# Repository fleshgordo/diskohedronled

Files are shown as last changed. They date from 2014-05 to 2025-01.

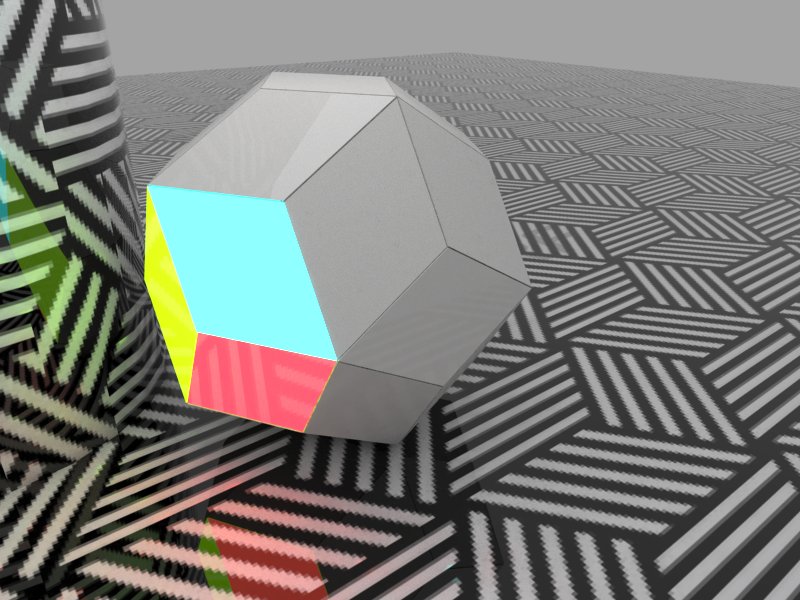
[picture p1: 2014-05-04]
construction/3dmodel/visualization/render-rgb-01.jpg

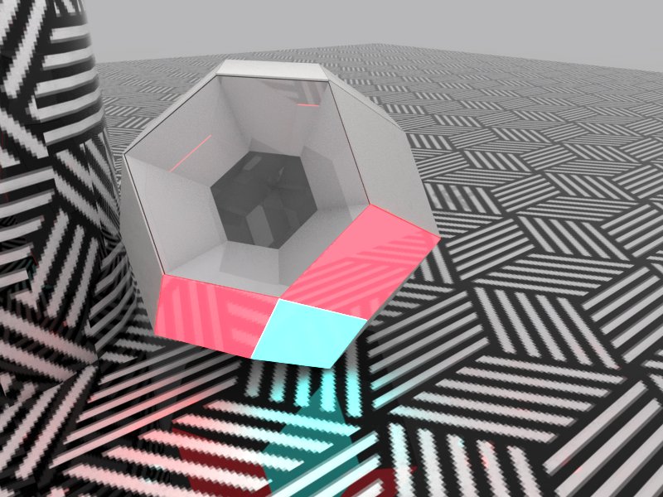
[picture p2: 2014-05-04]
construction/3dmodel/visualization/render-rgb-open.jpg

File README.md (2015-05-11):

Diskohedronled
==============

Diskohedron (led version) 2014

A triacontahedron with 30 laser-etched rhombic faces, each containing a 4W RGBW(+White) LED. The first prototype consists of 30 3d-printed rhombic boxes which form a Triacontahedron. 

  * 30 x 4W RGBW
  * WIFI interface (android/iphone controllable, served by nodejs on beaglebone black)
  * Modular
  
Thanks to Bread'n'Butter in Lausanne and HEAD Option interaction in Geneva for making us use their Makerbot printers.

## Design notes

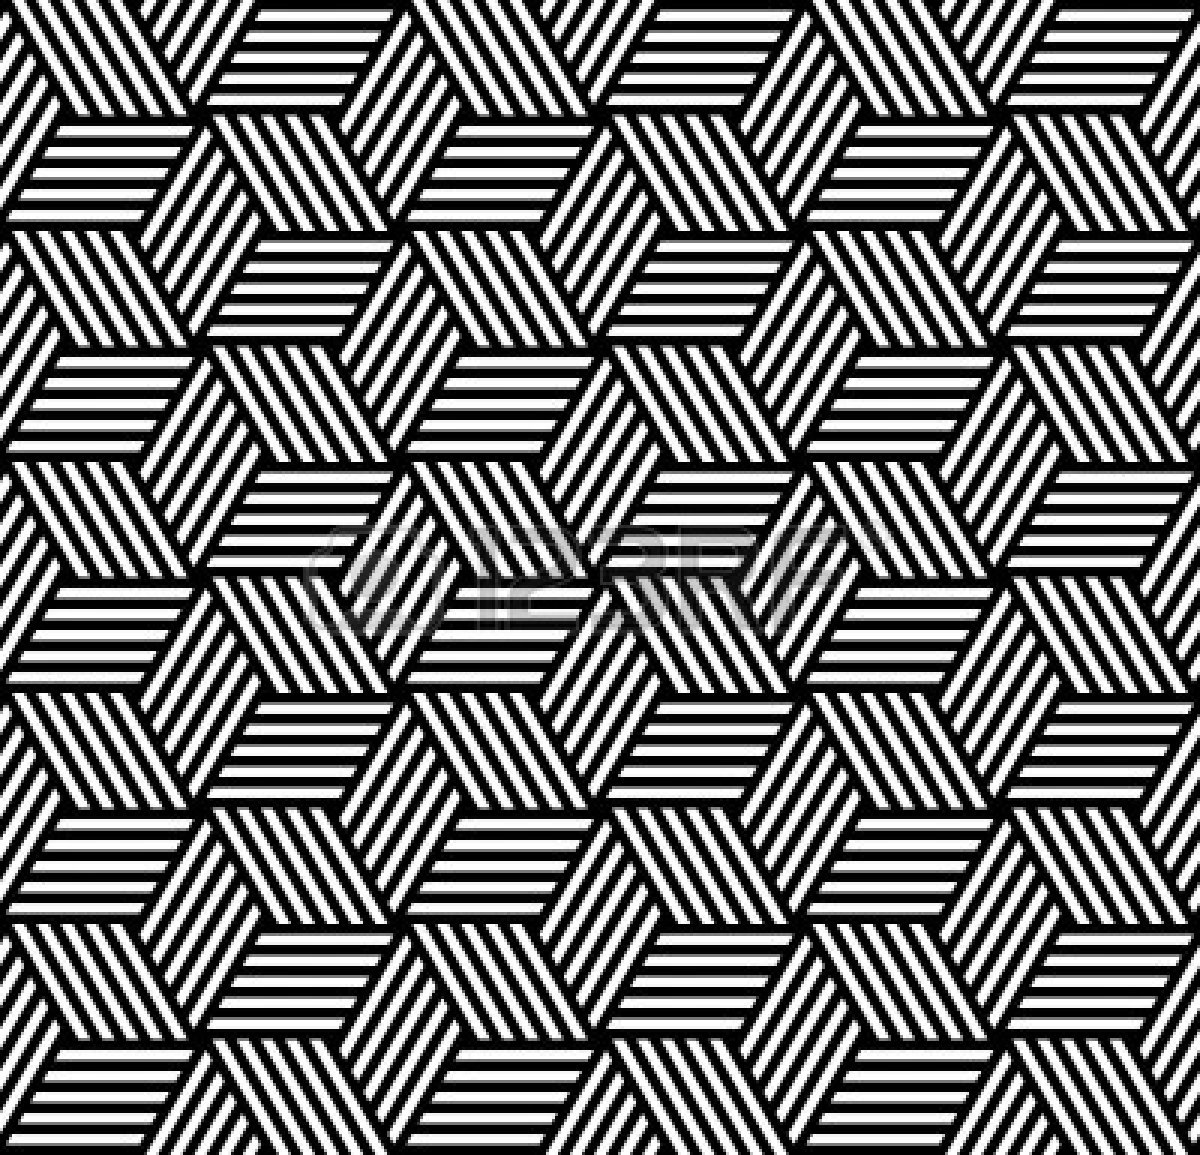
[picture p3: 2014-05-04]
construction/3dmodel/visualization/nahtlose-geometrische-muster-im-op-art-design.jpg

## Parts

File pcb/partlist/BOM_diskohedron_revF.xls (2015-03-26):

Ref | Value | Footprint | Manufacture | Manufacture Part Number | Quantity | Specification (mouser#)
1D | SN65LVDS1 | SOT23-5 | Texas Instruments | SN65LVDS1DBVR | 1 | 595-SN65LVDS1DBVR
4R | DS26LV32AT | SOIC16 | Texas Instruments | DS26LV32ATM/NOPB | 1 | 926-DS26LV32ATM/NOPB
C1 | 330uF | case G 10x10.2 | Panasonic | EEEFK1V331GP | 1 | 667-EEE-FK1V331GP
C2 | 330uF | case G 10x10.2 | Panasonic | EEEFK1V331GP | 1 | 667-EEE-FK1V331GP
C3 | 100n | C0805 | Vishay | VJ0805V104MXBP | 1 | 77-VJ0805V104MXBPBC
C4 | 100n | C0805 | Vishay | VJ0805V104MXBP | 1 | 77-VJ0805V104MXBPBC
D1 | 1N5824 3A | DIODE_SMC | Vishay | SS36-E3/57T | 1 | 625-SS36-E3
D2 | 1n4001 | SMADIODE | Taiwan Semiconductor | S1B | 1 | 512-S1B
JST | 8PIN-ZH | B8B-ZH |  | - | 1
L1 | 30uH | DR127 | Bussmann / Eaton | DR127-331-R | 1 | 704-DR127-331-R
LM2586 | LM2596 | TO263-5 | Texas Instruments | LM2596SX-3.3/NOPB | 1 | 926-LM2596SX33NOPB
R1 | 220R | M0805 | Vishay | CRCW0805220RF | 1 | 71-CRCW0805-220-E3
STP04 | STP04CM05 | TSSOP16 | STMicroelectronics | STP04CM0 | 1 | 511-STP04CM05XTTR
F1 | fuse | 1812 | Littelfuse | 1812L020PR | 1 | 576-1812L020PR
OUT-R | HERMAPHRODITMINI6PIN | HERMAPHRODITMINI6PIN | TE Connectivity | 1971567-3 | 1 | 571-1971567-3
POWEROUT-R | HERMAPHRODIT2PIN | HERMAPHRODIT2PIN | TE Connectivity | 1954289-1 | 1 | 571-1954289-1
IN1 | HERMAPHRODITMINI6PIN | HERMAPHRODITMINI6PIN | TE Connectivity | 1971567-3 | 1 | 571-1971567-3
POWERIN | HERMAPHRODIT2PIN | HERMAPHRODIT2PIN | TE Connectivity | 1954289-1 | 1 | 571-1954289-1

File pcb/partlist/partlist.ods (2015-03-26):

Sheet: costs_revd
Partlist
Exported from diskohedron4w_revd.sch at 15/11/14 8:38 AM
Part | Value | Device | Price | Package | Library | Mouser# | Manufactu
1D | SN65LVDS1 | SN65LVDS1 | $1.08 | SOT23-5 | diskohedron
4D | DS26LV31T | DS26LV31T |  | SOIC127P600X175-16N | Texas Instruments
4R | DS26LV32AT | DS26LV32AT | $1.39 | SOIC16 | diskohedron
C1 | 220uF | CPOL-EU175TMP-0810 | $0.28 | 175TMP-0810 | rcl | 140-VE221M1VTR0810 | VE-221M1VTR | http://www.ebay.com/itm/50-PCS-220UF-35V-SMD-Electrolytic-Capacitor-35V-220UF-8-10-/301202278340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
C2 | 220uF | CPOL-EU175TMP-0810 | $0.28 | 175TMP-0810 | rcl | 140-VE221M1VTR0810 | VE-221M1VTR
C3 | 100n | C-EUC0805 | $0.02 | C0805 | rcl | 77-VJ0805V104MXBPBC | VJ0805V104MXBP | http://www.ebay.com/itm/SMD-Chip-Capacitor-0805B104K-100nF-50V-100PCS-/371056581416?pt=LH_DefaultDomain_0
C4 | 100n | C-EUC0805 | $0.02 | C0805 | rcl | 77-VJ0805V104MXBPBC | VJ0805V104MXBP
D1 | 1N5824 3A | DIODE_E-SMC | $0.13 | DIODE_SMC | eagle-ltspice | 625-SS36-E3 | SS36-E3/57T
D2 | 1n4001 | DIODESMA | $0.03 | SMADIODE | adafruit | 821-S1BB | S1BB
JP1 | EXTBRD | M05PTH | $0.01 | 1X05 | SparkFun-Connectors
JST | 8PIN-ZH | 8PIN-ZH | $0.73 | B8B-ZH | diskohedron |  |  | http://www.ebay.com/itm/Micro-JST-1-5-ZH-8-Pin-Connector-Plug-with-Wire-x-10-sets-/121338507740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
L1 | 30uH | DR127 | $0.25 | DR127 | inductors | 704-DR127-331-R | DR127-331-R
LM2586 | LM2596 | LM2596S | $0.36 | TO263-5 | linear | 926-LM2596SX33NOPB | LM2596SX-3.3/NOPB | http://www.ebay.com/itm/50-PCS-LM2576S-3-3-TO-263-Step-Down-Voltage-Regulator-/301202266288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
R1 | 220R | R-EU_M0805 | $0.02 | M0805 | resistor | 71-CRCW0805-220-E3 | CRCW0805220RF | http://www.ebay.com/itm/50-220R-220-ohm-ohms-SMD-0805-Chip-Resistors-Surface-Mount-watts-5-/380905325760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
STP04 | STP04CM05 | STP04CM05 | $1.50 | TSSOP16 | stp04 | 511-STP04CM05XTTR | STP04CM0
IN1 | HERMAPHRODITMINI6PIN | HERMAPHRODITMINI6PIN | $0.50 | HERMAPHRODITMINI6PIN | diskohedron | 571-1971567-3 | 1971567-3
OUT-L | HERMAPHRODITMINI6PIN | HERMAPHRODITMINI6PIN | $0.50 | HERMAPHRODITMINI6PIN | diskohedron | 571-1971567-3 | 1971567-3
OUT-R | HERMAPHRODITMINI6PIN | HERMAPHRODITMINI6PIN |  | HERMAPHRODITMINI6PIN | diskohedron | 571-1971567-3 | 1971567-3
U$6 | HERMAPHRODIT2PIN | HERMAPHRODIT2PIN | $0.56 | HERMAPHRODIT2PIN | diskohedron | 571-1954289-1 | 1954289-1
U$7 | HERMAPHRODIT2PIN | HERMAPHRODIT2PIN | $0.56 | HERMAPHRODIT2PIN | diskohedron | 571-1954289-1 | 1954289-1
U$12 | HERMAPHRODIT2PIN | HERMAPHRODIT2PIN |  | HERMAPHRODIT2PIN | diskohedron | 571-1954289-1 | 1954289-1
F1 | FUSE | FUSE | $0.15 | 1812 | adafruit | 504-PTS181230V020 | PTS181230V020
 | 4W RGBW |  | $1.26
 | HEATSINK |  | $1.58
 | PLA-white 96g |  | $3.60
 | Acryl-glass Laser-cut |  | $3.00
 | PCB manufacturing |  | $4.20
 |  | Total par piece | $22.00
 |  | 30 pieces | $660.04
 |  | Power supply | $83.39
 |  | Microcontroller | $40.00
 |  | Cables, screws, glue | $20.00
 |  | Diskohedron in total | $825.43

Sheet: weight
 | in g
One module | 207
30 pcs. | 6210
Power supply | 325
Plastic Supply
Total | 6535

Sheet: costs_revb
Partlist
Exported from diskohedron4w_revb.sch at 6/4/14 8:38 AM
Part | Value | Device | Price | Package | Library | Mouser# | Manufactu
1D | SN65LVDS1 | SN65LVDS1 | $1.08 | SOT23-5 | diskohedron
4D | DS90LV047A | DS90LV047A |  |  | Texas Instruments
4R | DS26LV32AT | DS26LV32AT | $1.39 | SOIC16 | diskohedron
C1 | 220uF | CPOL-EU175TMP-0810 | $0.28 | 175TMP-0810 | rcl | 140-VE221M1VTR0810 | VE-221M1VTR | http://www.ebay.com/itm/50-PCS-220UF-35V-SMD-Electrolytic-Capacitor-35V-220UF-8-10-/301202278340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
C2 | 220uF | CPOL-EU175TMP-0810 | $0.28 | 175TMP-0810 | rcl | 140-VE221M1VTR0810 | VE-221M1VTR
C3 | 100n | C-EUC0805 | $0.02 | C0805 | rcl | 77-VJ0805V104MXBPBC | VJ0805V104MXBP | http://www.ebay.com/itm/SMD-Chip-Capacitor-0805B104K-100nF-50V-100PCS-/371056581416?pt=LH_DefaultDomain_0
C4 | 100n | C-EUC0805 | $0.02 | C0805 | rcl | 77-VJ0805V104MXBPBC | VJ0805V104MXBP
D1 | 1N5824 3A | DIODE_E-SMC | $0.13 | DIODE_SMC | eagle-ltspice | 625-SS36-E3 | SS36-E3/57T
D2 | 1n4001 | DIODESMA | $0.03 | SMADIODE | adafruit | 821-S1BB | S1BB
JP1 | EXTBRD | M05PTH | $0.01 | 1X05 | SparkFun-Connectors
JST | 8PIN-ZH | 8PIN-ZH | $0.73 | B8B-ZH | diskohedron | digikey 455-1663-ND | B8B-ZR(LF)(SN) | http://www.ebay.com/itm/Micro-JST-1-5-ZH-8-Pin-Connector-Plug-with-Wire-x-10-sets-/121338507740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
L1 | 30uH | DR127 | $0.25 | DR127 | inductors | 704-DR127-331-R | DR127-331-R
LM2586 | LM2596 | LM2596S | $0.36 | TO263-5 | linear | 926-LM2596SX33NOPB | LM2596SX-3.3/NOPB | http://www.ebay.com/itm/50-PCS-LM2576S-3-3-TO-263-Step-Down-Voltage-Regulator-/301202266288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
R1 | 220R | R-EU_M0805 | $0.02 | M0805 | resistor | 71-CRCW0805-220-E3 | CRCW0805220RF | http://www.ebay.com/itm/50-220R-220-ohm-ohms-SMD-0805-Chip-Resistors-Surface-Mount-watts-5-/380905325760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
STP04 | STP04CM05 | STP04CM05 | $1.50 | TSSOP16 | stp04 | 511-STP04CM05XTTR | STP04CM0
IN1 | HERMAPHRODITMINI6PIN | HERMAPHRODITMINI6PIN | $0.50 | HERMAPHRODITMINI6PIN | diskohedron | 571-1971567-3 | 1971567-3
OUT-L | HERMAPHRODITMINI6PIN | HERMAPHRODITMINI6PIN | $0.50 | HERMAPHRODITMINI6PIN | diskohedron | 571-1971567-3 | 1971567-3
OUT-R | HERMAPHRODITMINI6PIN | HERMAPHRODITMINI6PIN |  | HERMAPHRODITMINI6PIN | diskohedron | 571-1971567-3 | 1971567-3
U$6 | HERMAPHRODIT2PIN | HERMAPHRODIT2PIN | $0.56 | HERMAPHRODIT2PIN | diskohedron | 571-1954289-1 | 1954289-1
U$7 | HERMAPHRODIT2PIN | HERMAPHRODIT2PIN | $0.56 | HERMAPHRODIT2PIN | diskohedron | 571-1954289-1 | 1954289-1
U$12 | HERMAPHRODIT2PIN | HERMAPHRODIT2PIN |  | HERMAPHRODIT2PIN | diskohedron | 571-1954289-1 | 1954289-1
 | 4W RGBW
 | HEATSINK
 | PLA-white 96g
 | Acryl-glass Laser-cut
 | PCB manufacturing |  | $4.20
 | PCB Assembly
 |  | Total par piece | $12.41
 |  | 30 pieces | $372.43
 |  | Power supply | $83.39
 |  | Microcontroller | $40.00
 |  | Cables, screws, glue | $20.00
 |  | Diskohedron in total | $528.23

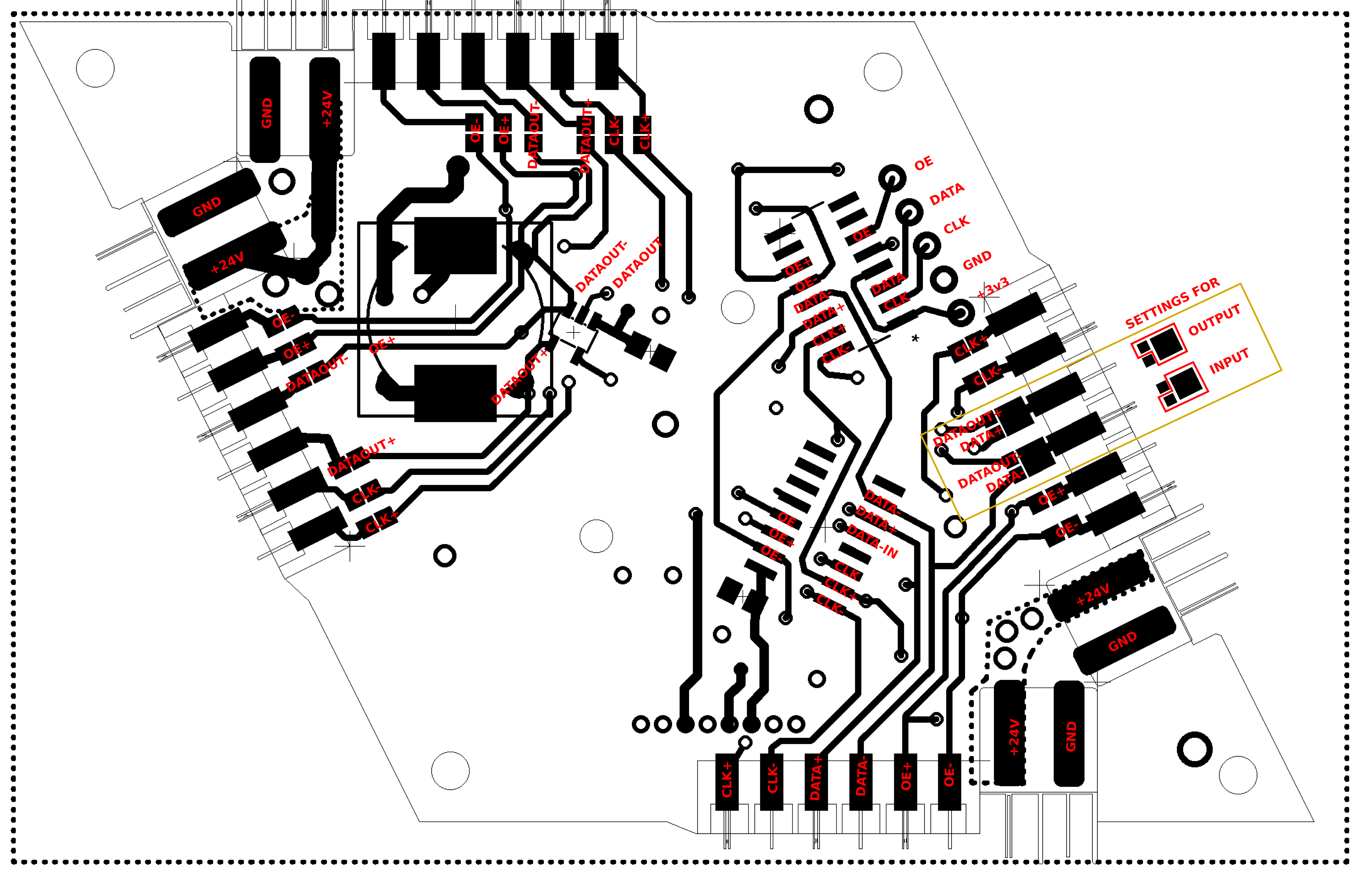
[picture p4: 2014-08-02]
pcb/partlist/MountingBottomrevc.png

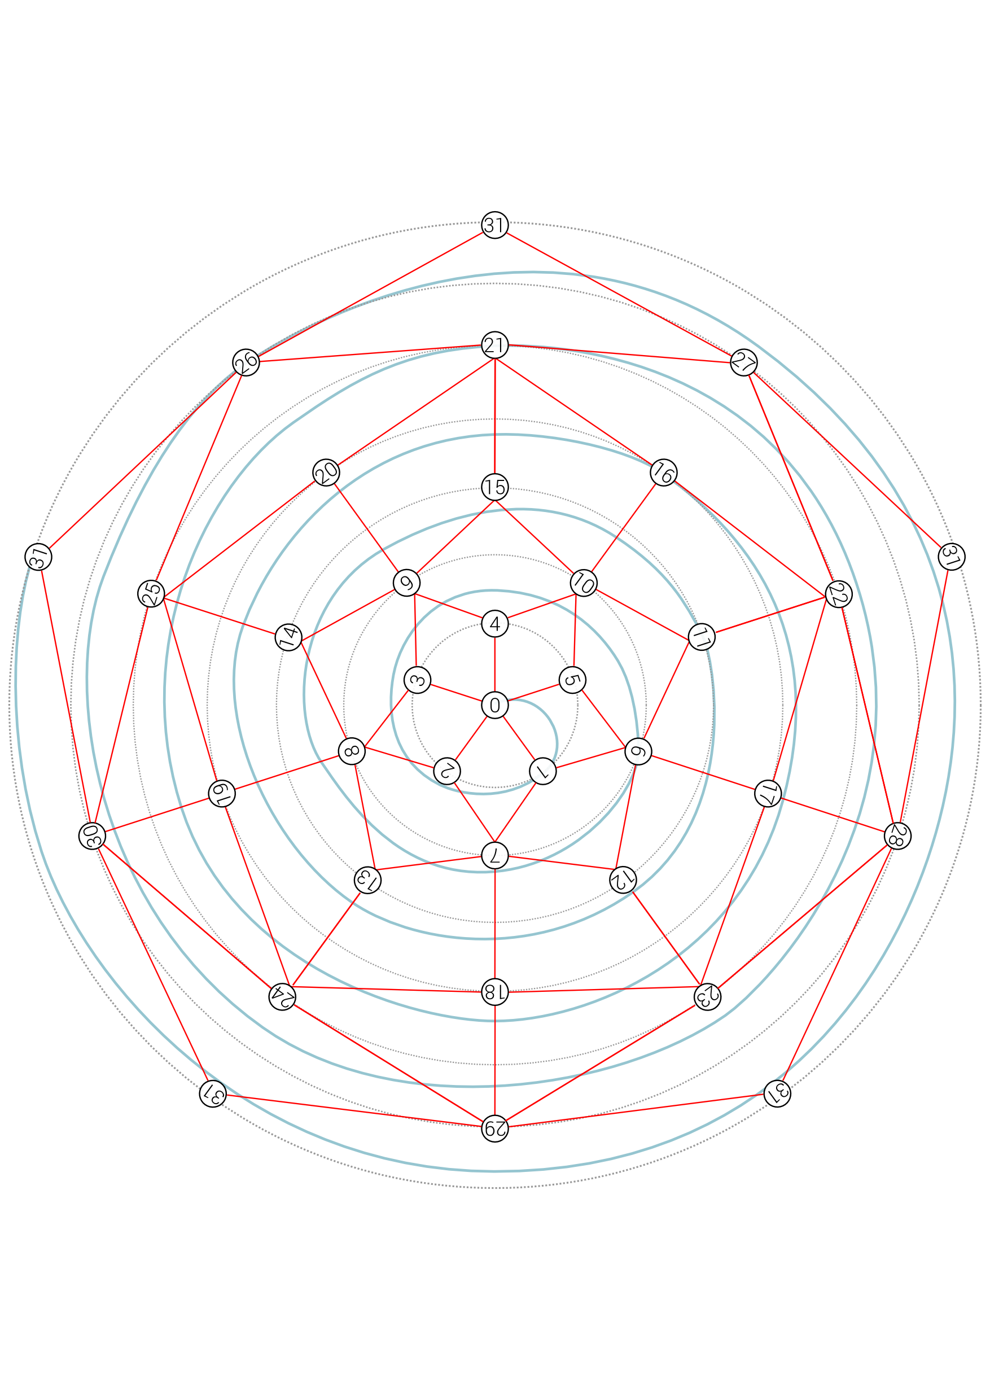
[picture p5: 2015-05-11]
software/zwart-order.png

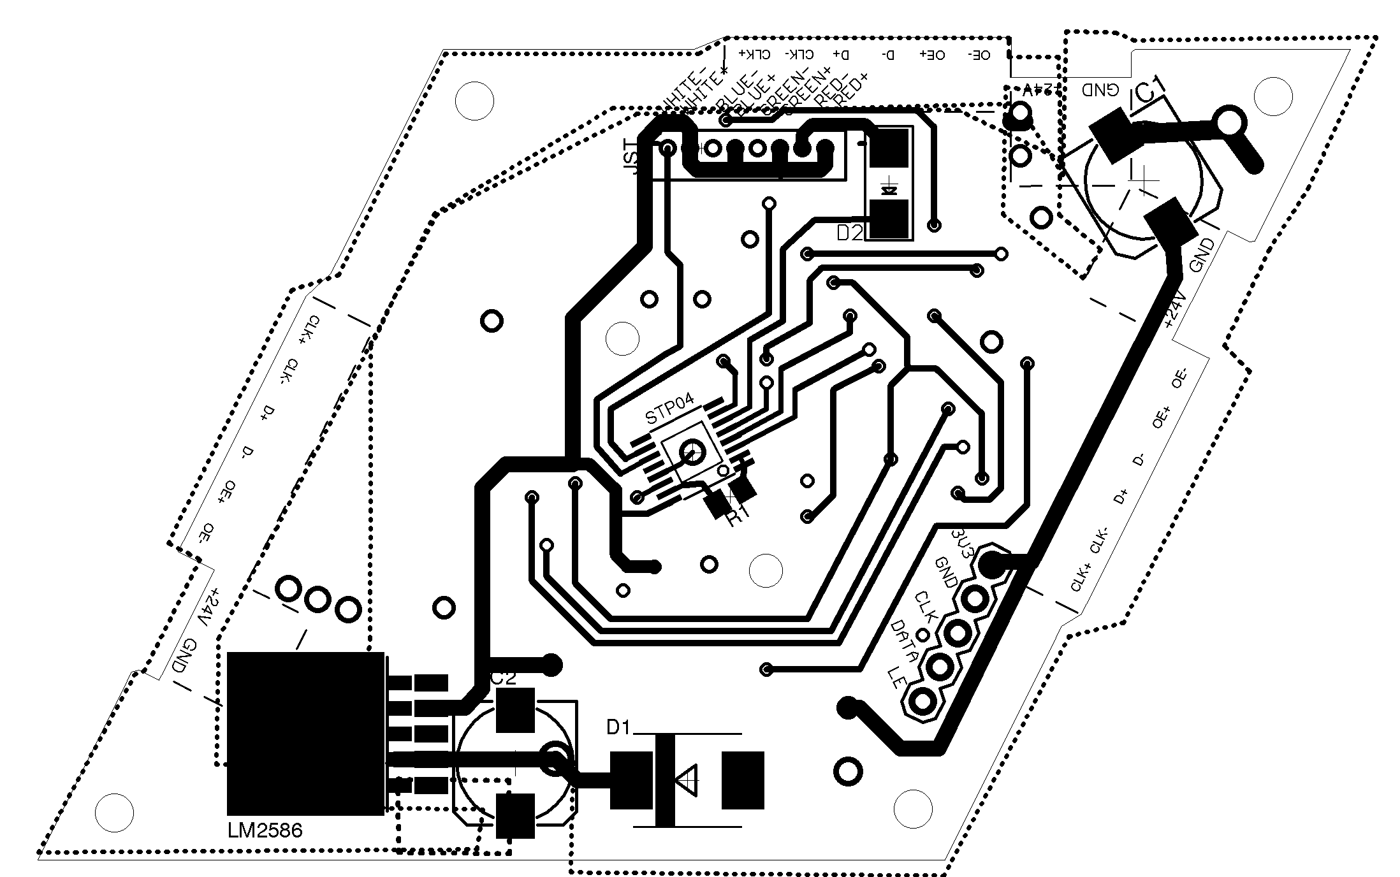
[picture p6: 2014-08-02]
pcb/partlist/MountingToprevb.png

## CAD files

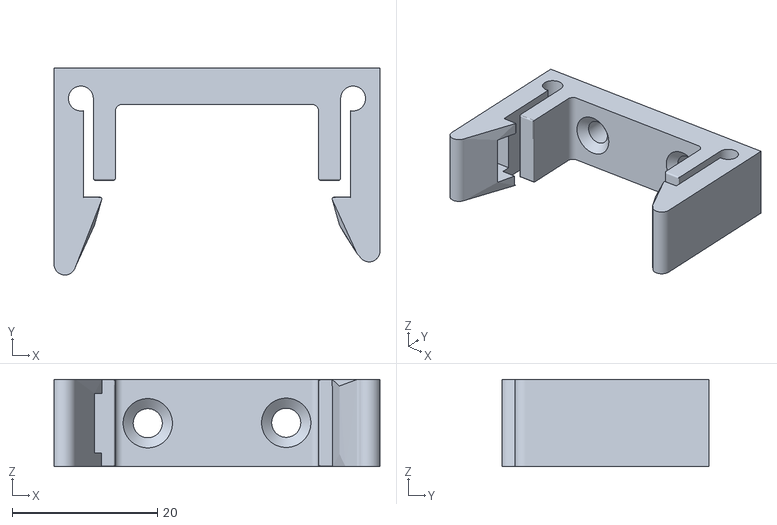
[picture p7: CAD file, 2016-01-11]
construction/3dmodel/teensy-revision.stl
44.9 x 28.5 x 12.0

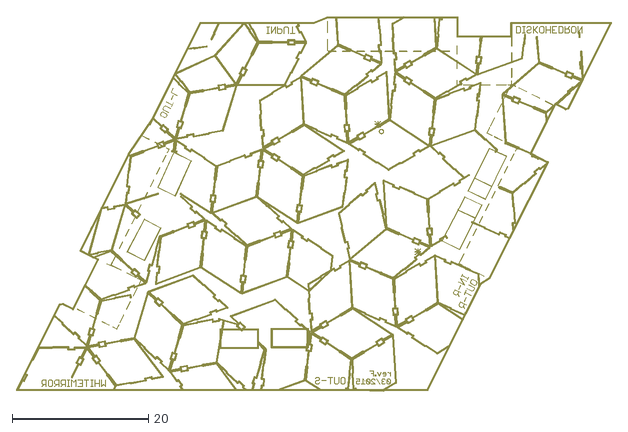
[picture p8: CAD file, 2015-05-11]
pcb/diskohedron4w_revf.dxf
87.4 x 55.0

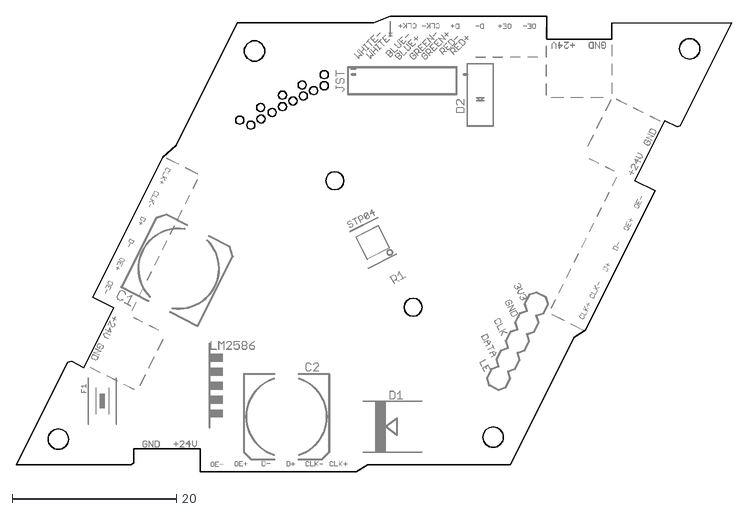
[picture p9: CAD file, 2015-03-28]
pcb/screenshots/diskohedron4w_revf.dxf
87.2 x 55.5

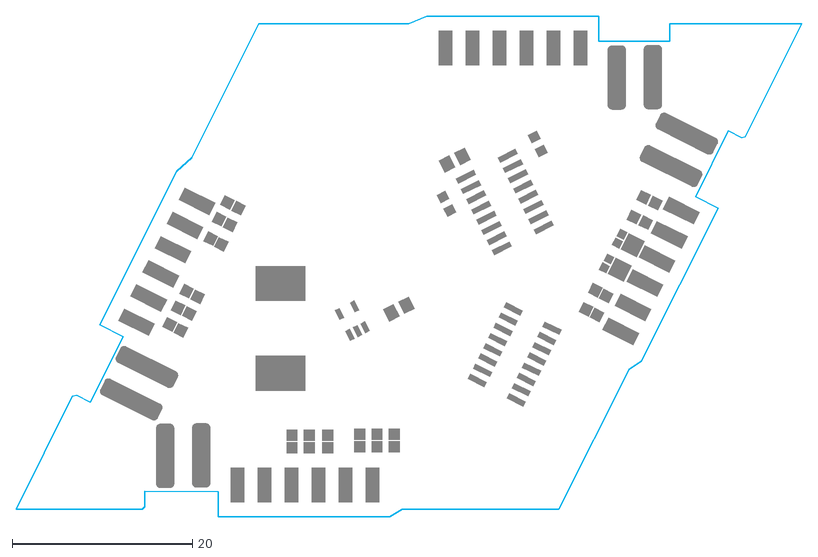
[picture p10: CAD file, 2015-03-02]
pcb/stencil/revd_Bcream.dxf
87.2 x 55.5

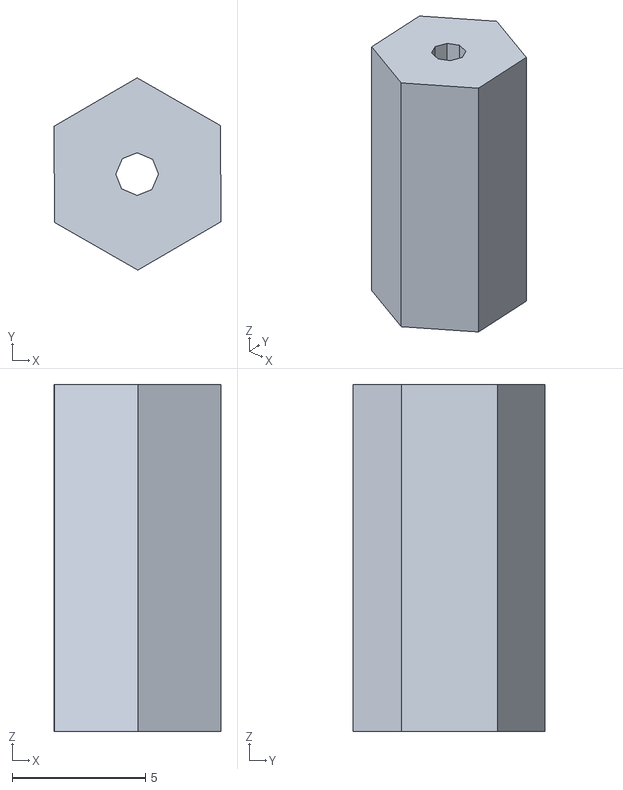
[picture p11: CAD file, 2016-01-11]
construction/3dmodel/standoff-13mm.stl
6.25 x 7.20 x 13.0

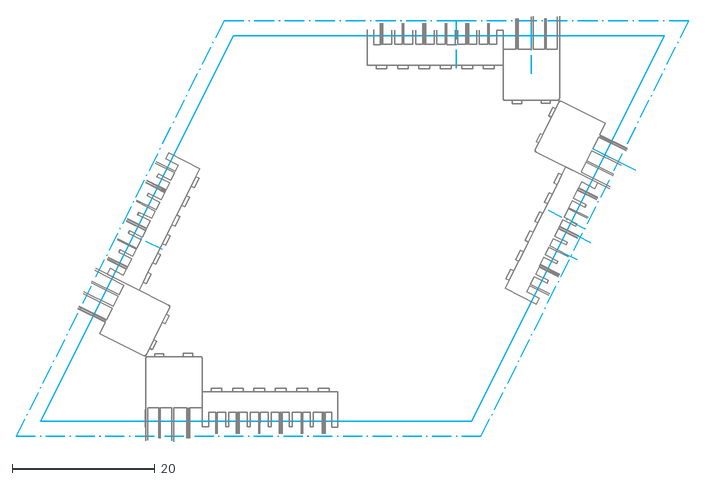
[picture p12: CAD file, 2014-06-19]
construction/diskohedron4w_hermaphrodit-plug_positions_R12.dxf
94.1 x 59.5

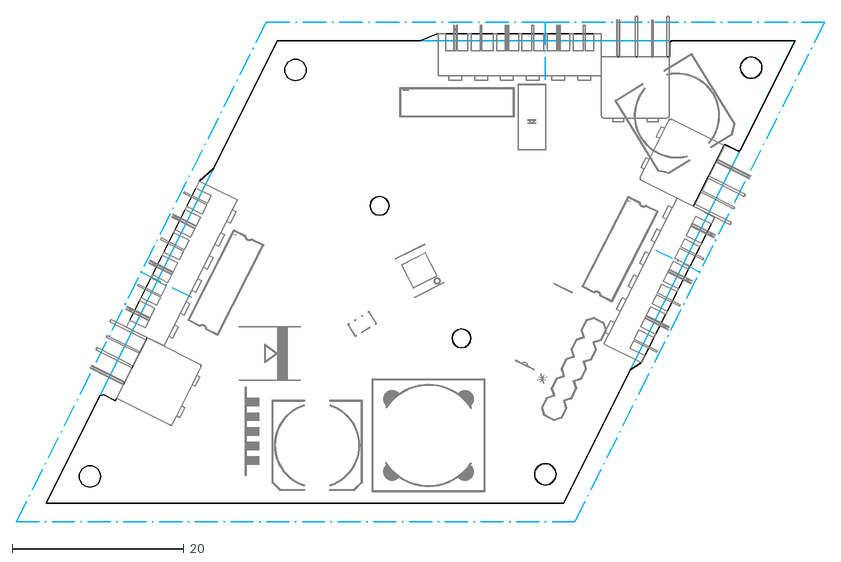
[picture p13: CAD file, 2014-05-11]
pcb/diskohedron4w_hermaphrodit.dxf
94.1 x 58.9

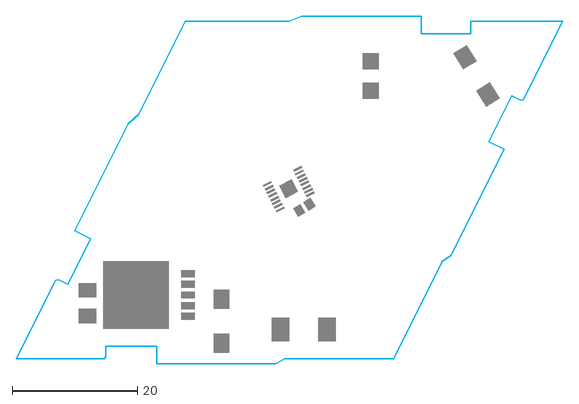
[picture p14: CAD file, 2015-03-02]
pcb/stencil/revd_Tcream.dxf
87.2 x 55.5

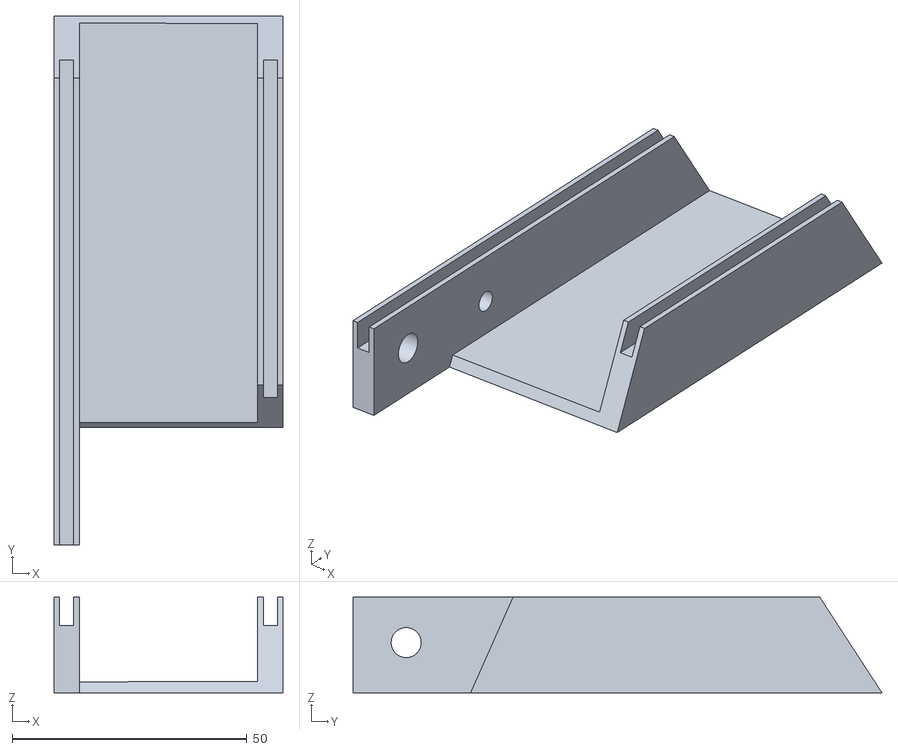
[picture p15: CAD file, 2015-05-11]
construction/3dmodel/powerbox-wallmount-L.stl
48.8 x 112.7 x 20.4

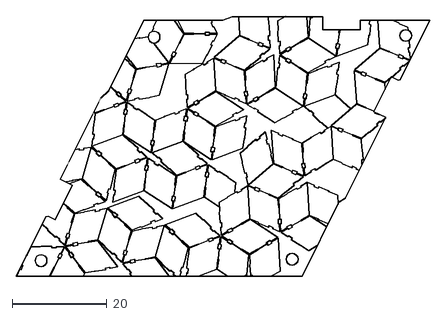
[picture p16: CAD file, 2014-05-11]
construction/diskohedron4w_pattern.dxf
87.2 x 54.8

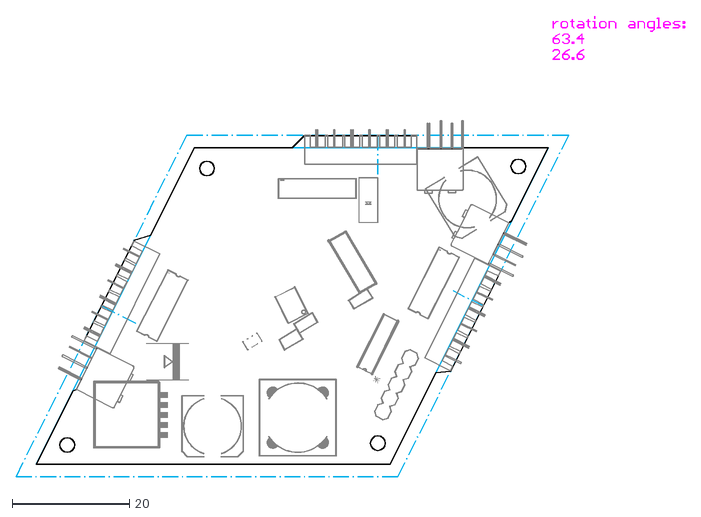
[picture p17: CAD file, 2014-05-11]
pcb/diskohedron4w_partoutline.dxf
113.9 x 78.4

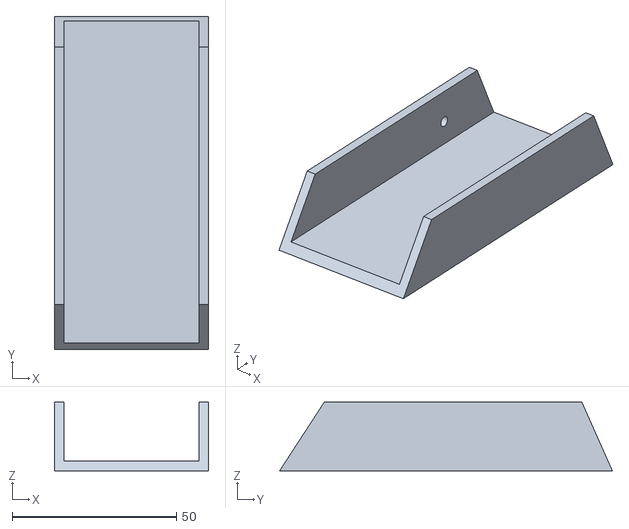
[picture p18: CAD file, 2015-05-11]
construction/3dmodel/powerbox-wallmount-R.stl
47.0 x 101.4 x 21.0

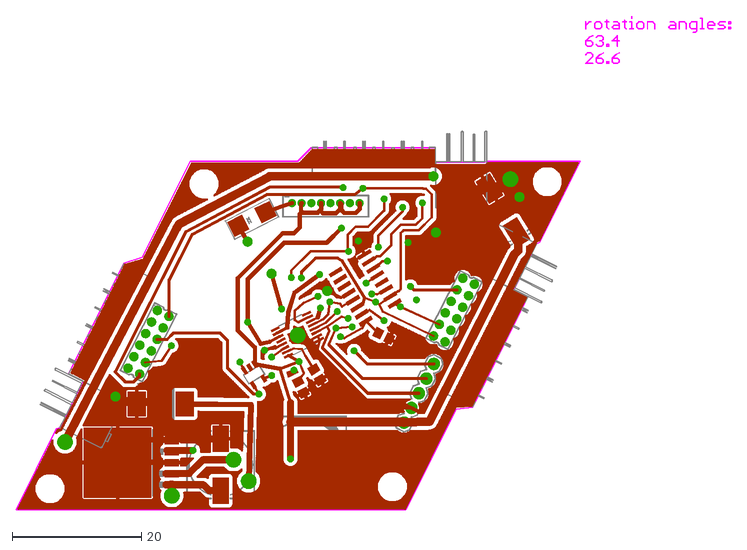
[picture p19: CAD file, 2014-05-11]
construction/diskohedron4w_hermaphrodit.dxf
110.5 x 76.3

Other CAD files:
construction/lasercutting/face-revB-versalaser-sheet.dwg
construction/PowerSupply.dxf
construction/short cuts/room-layout-elements.dwg
construction/lasercutting/face-revB-powerunitcone.dxf
pcb/stencil/revc_revb_laser-layout.dwg
construction/3dmodel/TeensyHolder108.stl
construction/3dmodel/diskohedron4w_revc.dxf
construction/3dmodel/piramida-bb.stl
construction/3dmodel/piramida-revA.skp
construction/3dmodel/piramida-revB-2boxes-3Dutility.stl
construction/3dmodel/piramida-revB-3dutility.stl
construction/3dmodel/piramida-revB.stl
construction/3dmodel/piramida-revF-1-6-mesh.stl
construction/3dmodel/piramida-revF-1-6.stl
construction/3dmodel/piramida-revF-mesh.stl
construction/3dmodel/piramida-revF-test.3dm
construction/3dmodel/piramida-revF.stl
construction/3dmodel/piramida.skp
construction/3dmodel/power-rupe.3dm
construction/3dmodel/powerbox-wallmount.3dm
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

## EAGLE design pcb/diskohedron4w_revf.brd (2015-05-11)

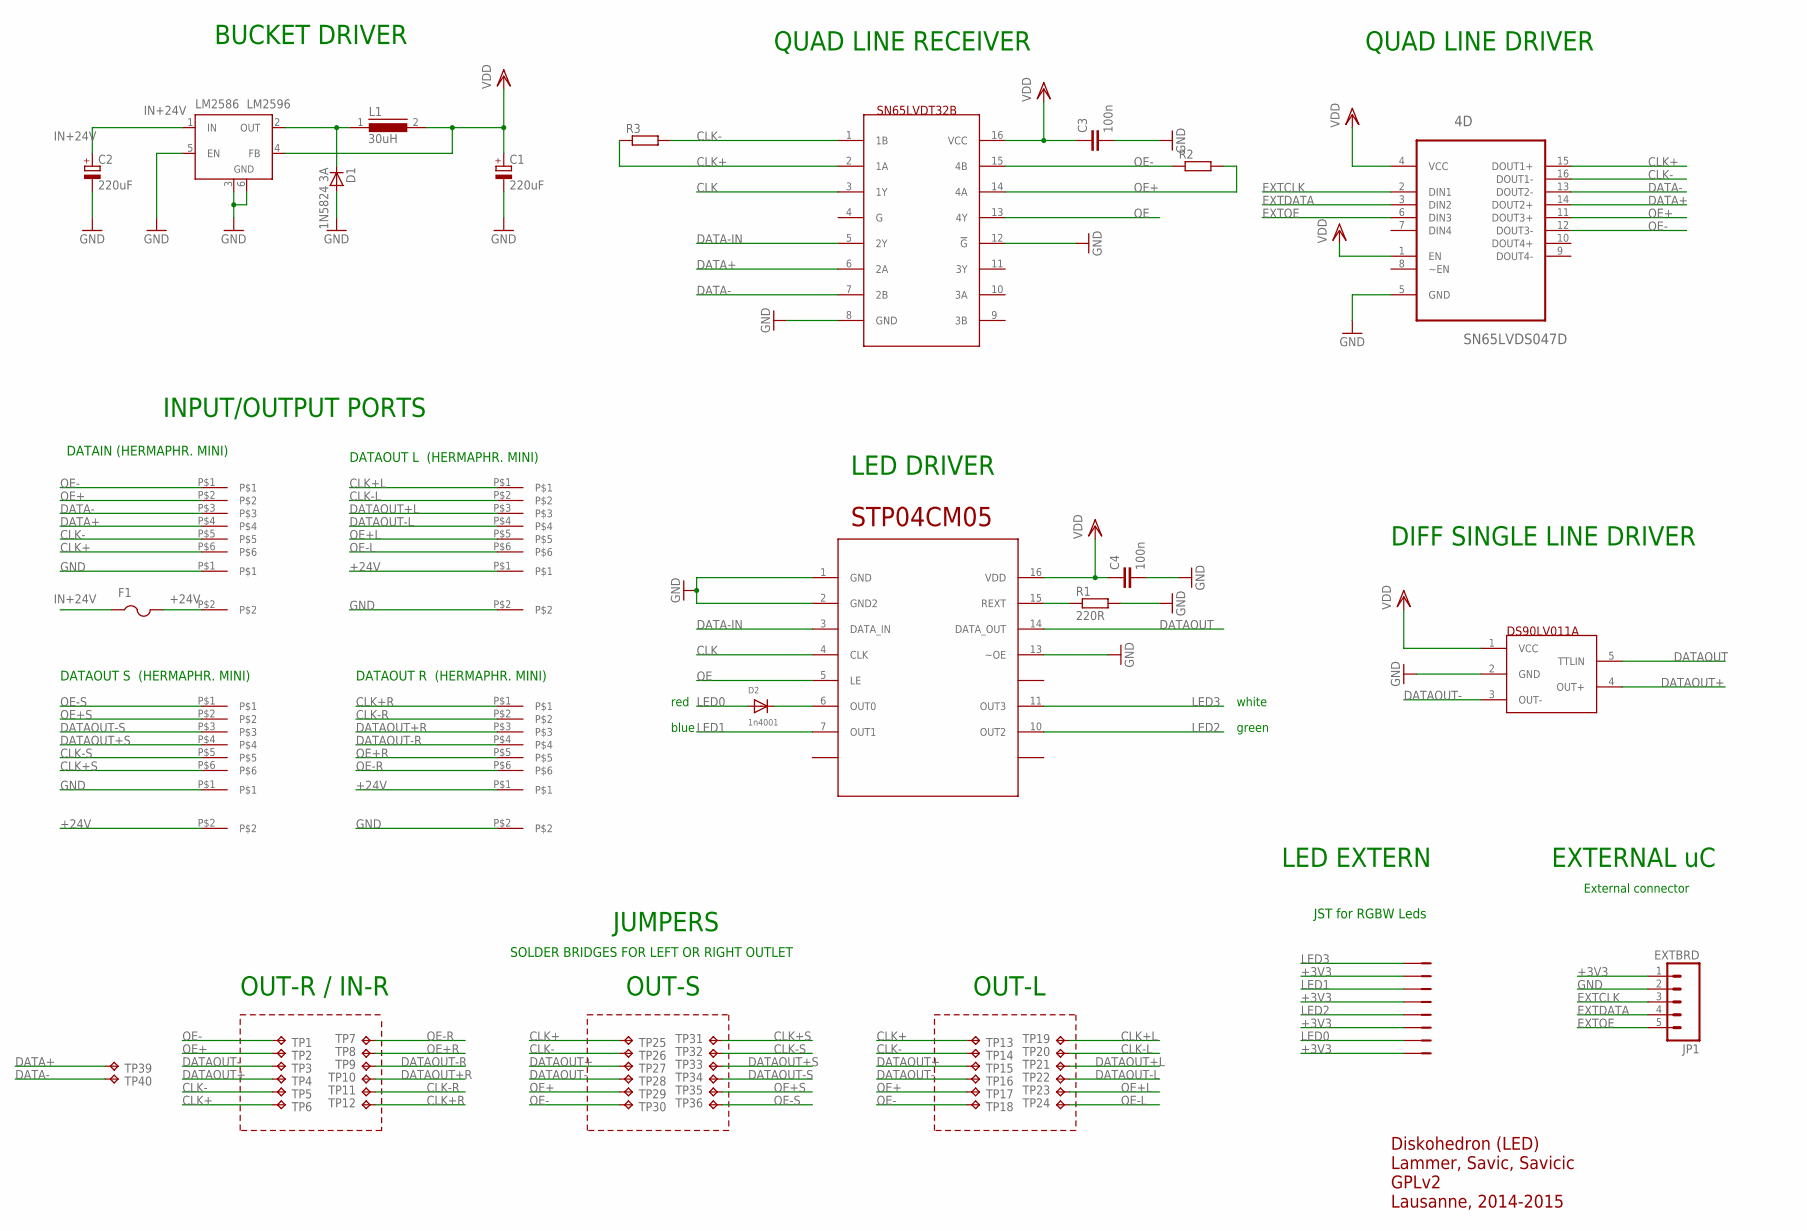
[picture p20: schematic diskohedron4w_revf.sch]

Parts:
1D: DS90LV011A; SOT23-5
4D: SN65LVDS047D; SOIC127P600X175-16N
4R: SN65LVDST32; SOIC16
C1, C2: 220uF; 153CLV-1010
C3, C4: 100n; C0805
D1: 1N5824 3A; DIODE_SMC
D2: 1n4001; SMADIODE
F1: PTCFUSE-1812; 1812
IN1: HERMAPHRODITMINI6PIN
JP1: EXTBRD; 1X05
JST: 8PIN-ZH; B8B-ZH
L1: 30uH; DR127
LM2586: LM2596; TO263-5
OUT-L: HERMAPHRODITMINI6PIN
OUT-R: HERMAPHRODITMINI6PIN
OUT-S: HERMAPHRODITMINI6PIN
POWERIN: HERMAPHRODIT2PIN
POWEROUT-L: HERMAPHRODIT2PIN
POWEROUT-R: HERMAPHRODIT2PIN
POWEROUT-S: HERMAPHRODIT2PIN
R1: 220R; M0805
R2, R3: R-EU_R0603; R0603
STP04: STP04CM05; TSSOP16
TP1, TP2, TP5, TP6, TP7, TP8, TP11, TP12, TP13, TP14, TP15, TP16, TP17, TP18, TP19, TP20, TP21, TP22, TP23, TP24, TP25, TP26, TP27, TP28, TP29, TP30, TP31, TP32, TP33, TP34, TP35, TP36: TPTP12SQ; TP12SQ
TP3, TP4, TP39, TP40: TPTP09SQ; TP09SQ
TP9, TP10: TPTP20SQ; TP20SQ

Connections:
+3V3: 1D.1 (VCC), 4D.1 (EN), 4D.4 (VCC), 4R.16 (VCC), C1.+, C3.1, C4.1, JP1.1, JST.2, JST.4, JST.6, JST.8, L1.2, LM2586.4 (FB), STP04.16 (VDD)
+24V: F1.2, POWERIN.P$2, POWEROUT-L.P$1, POWEROUT-R.P$1, POWEROUT-S.P$2
CLK: 4R.3 (1Y), STP04.4 (CLK)
CLK+: 4D.15 (DOUT1+), 4R.2 (1A), IN1.P$6, R3.1, TP6.TP, TP13.TP, TP25.TP
CLK+L: OUT-L.P$1, TP19.TP
CLK+R: OUT-R.P$1, TP12.TP
CLK+S: OUT-S.P$6, TP31.TP
CLK-: 4D.16 (DOUT1-), 4R.1 (1B), IN1.P$5, R3.2, TP5.TP, TP14.TP, TP26.TP
CLK-L: OUT-L.P$2, TP20.TP
CLK-R: OUT-R.P$2, TP11.TP
CLK-S: OUT-S.P$5, TP32.TP
DATA+: 4D.14 (DOUT2+), 4R.6 (2A), IN1.P$4, TP39.TP
DATA-: 4D.13 (DOUT2-), 4R.7 (2B), IN1.P$3, TP40.TP
DATA-IN: 4R.5 (2Y), STP04.3 (DATA_IN)
DATAOUT: 1D.5 (TTLIN), STP04.14 (DATA_OUT)
DATAOUT+: 1D.4 (OUT+), TP4.TP, TP15.TP, TP27.TP
DATAOUT+L: OUT-L.P$3, TP21.TP
DATAOUT+R: OUT-R.P$3, TP10.TP
DATAOUT+S: OUT-S.P$4, TP33.TP
DATAOUT-: 1D.3 (OUT-), TP3.TP, TP16.TP, TP28.TP
DATAOUT-L: OUT-L.P$4, TP22.TP
DATAOUT-R: OUT-R.P$4, TP9.TP
DATAOUT-S: OUT-S.P$3, TP34.TP
EXTCLK: 4D.2 (DIN1), JP1.3
EXTDATA: 4D.3 (DIN2), JP1.4
EXTOE: 4D.6 (DIN3), JP1.5
GND: 1D.2 (GND), 4D.5 (GND), 4R.8 (GND), 4R.12 (!G), C1.-, C2.-, C3.2, C4.2, D1.A (C), JP1.2, LM2586.3 (GND), LM2586.5 (EN), LM2586.6 (GND), POWERIN.P$1, POWEROUT-L.P$2, POWEROUT-R.P$2, POWEROUT-S.P$1, R1.2, STP04.1 (GND), STP04.2 (GND2), STP04.13 (~OE)
IN+24V: C2.+, F1.1, LM2586.1 (IN)
LED0: D2.A, JST.7
LED1: JST.3, STP04.7 (OUT1)
LED2: JST.5, STP04.10 (OUT2)
LED3: JST.1, STP04.11 (OUT3)
unnamed: R1.1, STP04.15 (REXT)
unnamed: D1.C (A), L1.1, LM2586.2 (OUT)
unnamed: D2.C, STP04.6 (OUT0)
OE: 4R.13 (4Y), STP04.5 (LE)
OE+: 4D.11 (DOUT3+), 4R.14 (4A), IN1.P$2, R2.2, TP2.TP, TP17.TP, TP29.TP
OE+L: OUT-L.P$5, TP23.TP
OE+R: OUT-R.P$5, TP8.TP
OE+S: OUT-S.P$2, TP35.TP
OE-: 4D.12 (DOUT3-), 4R.15 (4B), IN1.P$1, R2.1, TP1.TP, TP18.TP, TP30.TP
OE-L: OUT-L.P$6, TP24.TP
OE-R: OUT-R.P$6, TP7.TP
OE-S: OUT-S.P$1, TP36.TP

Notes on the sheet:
QUAD LINE RECEIVER
LED DRIVER
DIFF SINGLE LINE DRIVER
BUCKET DRIVER
DATAOUT L (HERMAPHR. MINI)
DATAOUT R (HERMAPHR. MINI)
DATAIN (HERMAPHR. MINI)
External connector
JST for RGBW Leds
SOLDER BRIDGES FOR LEFT OR RIGHT OUTLET
JUMPERS
Diskohedron (LED) Lammer, Savic, Savicic GPLv2 Lausanne, 2014-2015
QUAD LINE DRIVER
INPUT/OUTPUT PORTS
EXTERNAL uC
red
blue
green
white
DATAOUT S (HERMAPHR. MINI)
OUT-R / IN-R
OUT-S
OUT-L
LED EXTERN

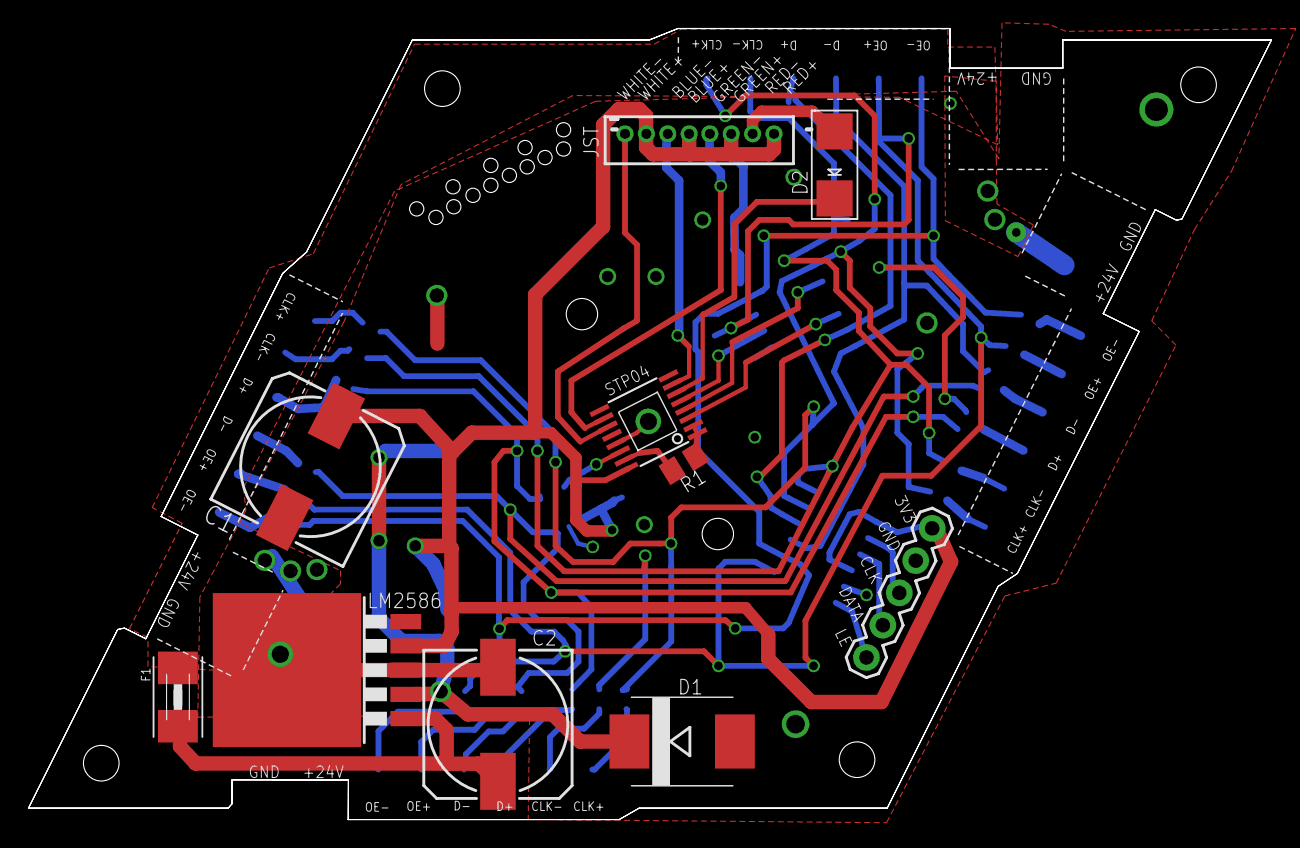
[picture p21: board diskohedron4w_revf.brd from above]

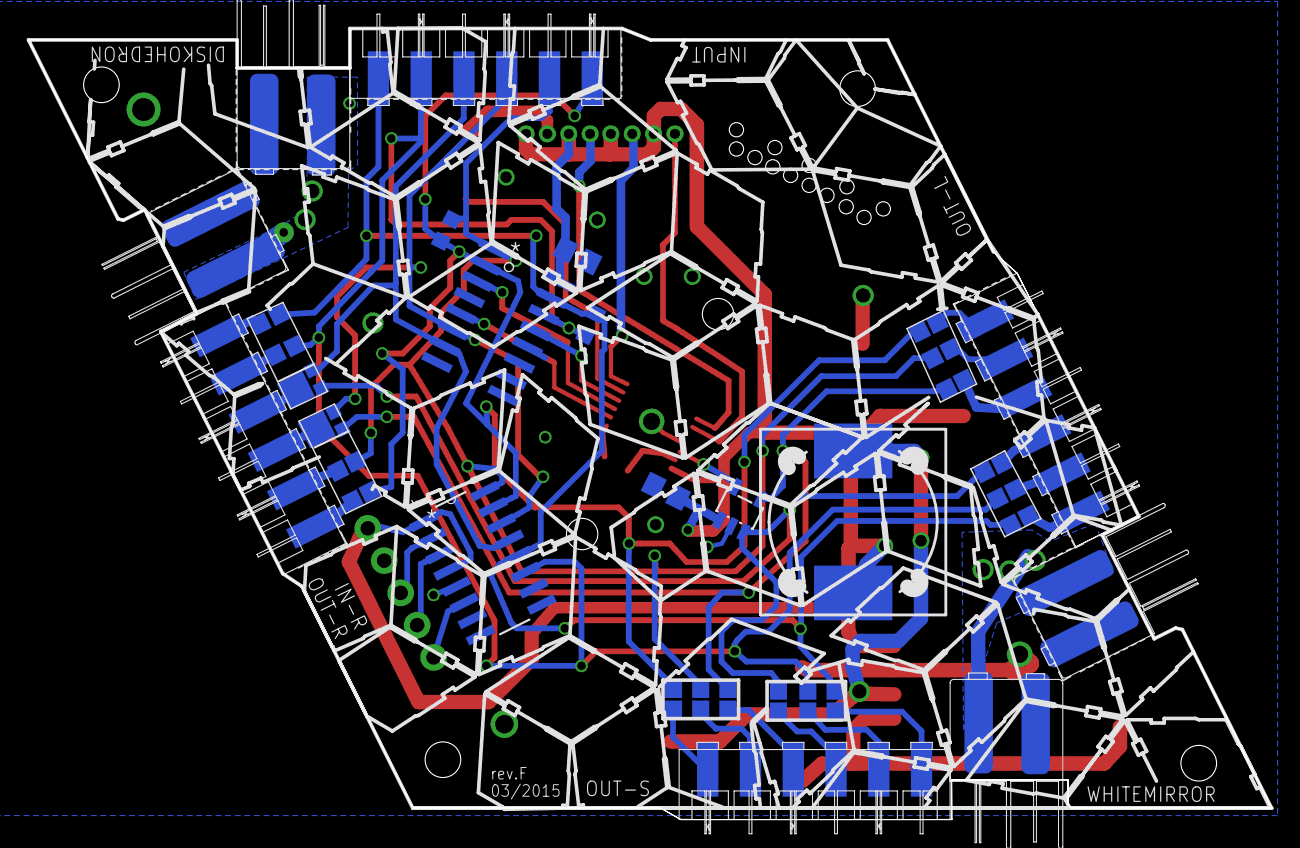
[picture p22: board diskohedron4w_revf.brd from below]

Board: 2 copper layers, 87.2 x 55.5 mm, 64 parts (54 on the bottom side), 44 nets.

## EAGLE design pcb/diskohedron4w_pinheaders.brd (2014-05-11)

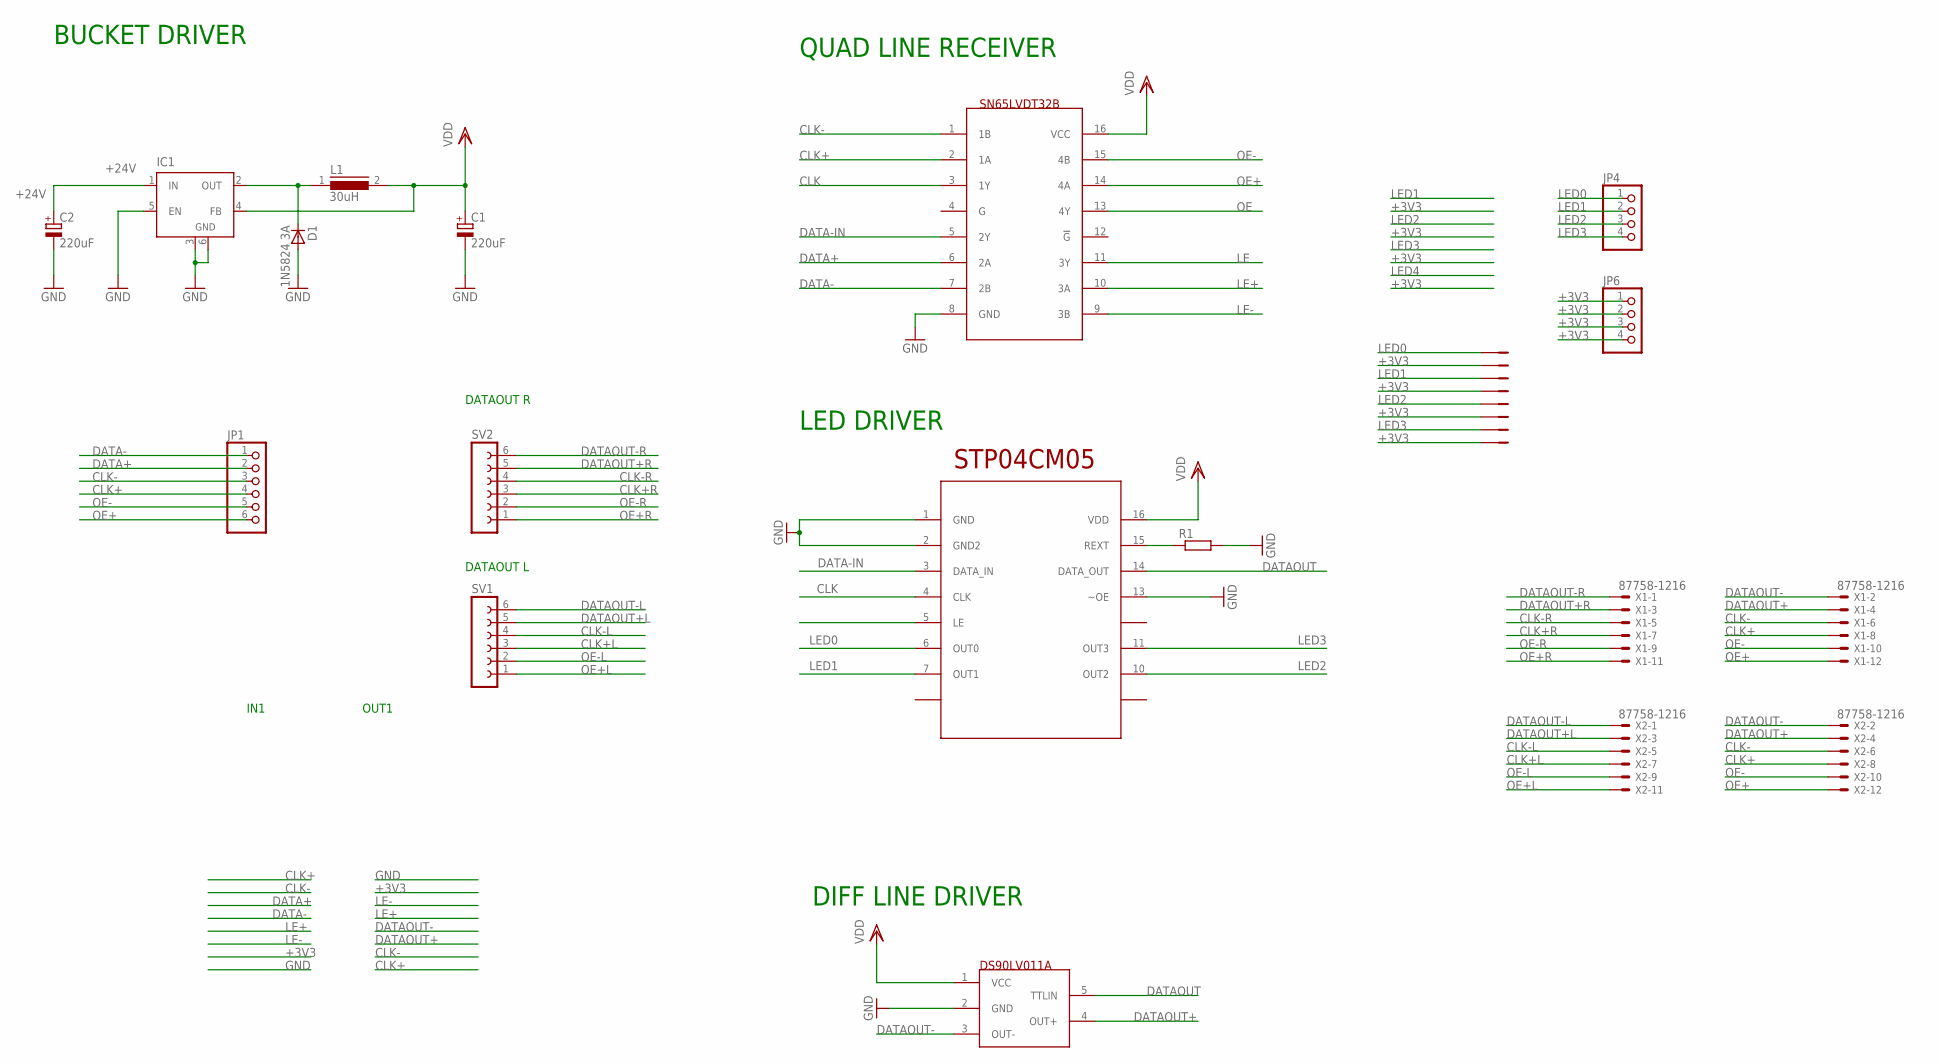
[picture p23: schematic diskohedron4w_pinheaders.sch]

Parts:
C1, C2: 220uF; 153CLV-1010
D1: 1N5824 3A; DIODE_SMC
IC1: LM2596S; TO263-5
JP1: PINHD-1X06_2.54-90°; 1X06/90
JP4, JP6: PINHD-1X4; 1X04
L1: 30uH; DR127
R1: R-EU_M0805; M0805
SV1, SV2: FE06W
U$1: STP04CM05; TSSOP16
U$2: SN65LVDST32; SOIC16
U$3: DS90LV011A; SOT23-5
U$4: 8PIN-ZH; B8B-ZH
X1, X2: 87758-1216

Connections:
+3V3: C1.+, IC1.4 (FB), JP6.1, JP6.2, JP6.3, JP6.4, L1.2, U$1.16 (VDD), U$2.16 (VCC), U$3.1 (VCC), U$4.2, U$4.4, U$4.6, U$4.8
+24V: C2.+, IC1.1 (IN)
CLK: U$1.4 (CLK), U$2.3 (1Y)
CLK+: JP1.4, U$2.2 (1A), X1.8, X2.8
CLK+L: SV1.3, X2.7
CLK+R: SV2.3, X1.7
CLK-: JP1.3, U$2.1 (1B), X1.6, X2.6
CLK-L: SV1.4, X2.5
CLK-R: SV2.4, X1.5
DATA+: JP1.2, U$2.6 (2A)
DATA-: JP1.1, U$2.7 (2B)
DATA-IN: U$1.3 (DATA_IN), U$2.5 (2Y)
DATAOUT: U$1.14 (DATA_OUT), U$3.5 (TTLIN)
DATAOUT+: U$3.4 (OUT+), X1.4, X2.4
DATAOUT+L: SV1.5, X2.3
DATAOUT+R: SV2.5, X1.3
DATAOUT-: U$3.3 (OUT-), X1.2, X2.2
DATAOUT-L: SV1.6, X2.1
DATAOUT-R: SV2.6, X1.1
GND: C1.-, C2.-, D1.A (C), IC1.3 (GND), IC1.5 (EN), IC1.6 (GND), R1.2, U$1.1 (GND), U$1.2 (GND2), U$1.13 (~OE), U$2.8 (GND), U$3.2 (GND)
LE: U$1.5 (LE), U$2.11 (3Y)
LE+: U$2.10 (3A)
LE-: U$2.9 (3B)
LED0: JP4.1, U$1.6 (OUT0), U$4.1
LED1: JP4.2, U$1.7 (OUT1), U$4.3
LED2: JP4.3, U$1.10 (OUT2), U$4.5
LED3: JP4.4, U$1.11 (OUT3), U$4.7
unnamed: R1.1, U$1.15 (REXT)
unnamed: D1.C (A), IC1.2 (OUT), L1.1
OE: U$2.13 (4Y)
OE+: JP1.6, U$2.14 (4A), X1.12, X2.12
OE+L: SV1.1, X2.11
OE+R: SV2.1, X1.11
OE-: JP1.5, U$2.15 (4B), X1.10, X2.10
OE-L: SV1.2, X2.9
OE-R: SV2.2, X1.9

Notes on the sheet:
QUAD LINE RECEIVER
LED DRIVER
DIFF LINE DRIVER
IN1
OUT1
BUCKET DRIVER
DATAOUT L
DATAOUT R

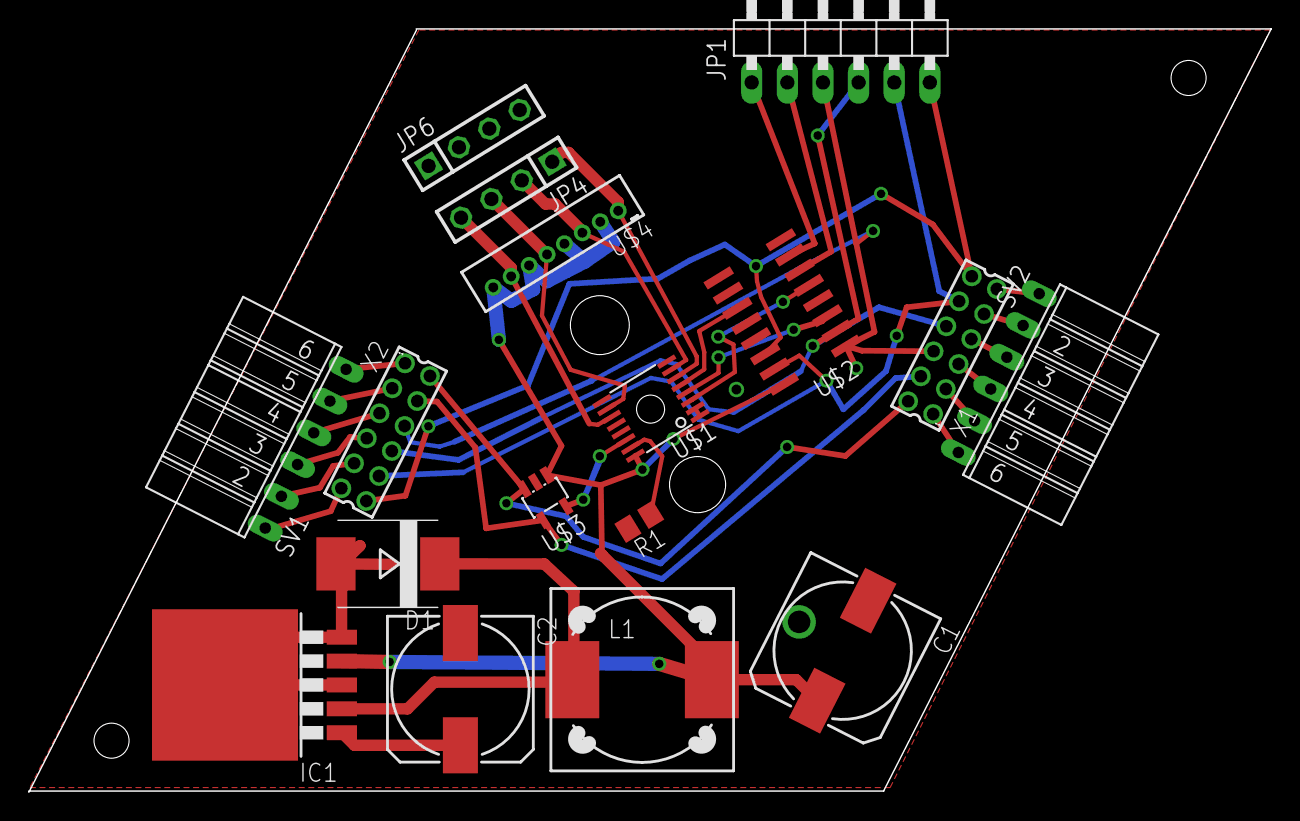
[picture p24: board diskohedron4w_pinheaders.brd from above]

Board: 2 copper layers, 88.6 x 54.4 mm, 17 parts (0 on the bottom side), 33 nets.

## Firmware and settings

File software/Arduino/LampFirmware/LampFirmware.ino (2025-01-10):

const int ShiftPWM_latchPin = 8;
const bool ShiftPWM_invertOutputs = false;
const bool ShiftPWM_balanceLoad = false;

#include <ShiftPWM.h>  // include ShiftPWM.h after setting the pins!

unsigned char maxBrightness = 165;
unsigned char pwmFrequency = 60;

int numRGBleds = 30;

int bitsPerBoard = 4;
int registerSize = 8;

int numRegisters = (numRGBleds + 1) * bitsPerBoard / registerSize;

int heartbeat = 0;

const int N1 = 0;
const int N2 = 1;
const int N3 = 2;
const int N4 = 3;
const int TR = 0;
const int TG = 1;
const int TB = 2;
const int TW = 3;


const byte LED_R = B10000000;
const byte LED_G = B01000000;
const byte LED_B = B00100000;
const byte LED_W = B00010000;
const byte DIR_1 = B00001000;
const byte DIR_2 = B00000100;
const byte DIR_3 = B00000010;
const byte DIR_4 = B00000001;


const byte RECEIVING_N = 0;
const byte RECEIVING_R = 1;
const byte RECEIVING_G = 2;
const byte RECEIVING_B = 3;
const byte RECEIVING_W = 4;
byte receiving = RECEIVING_N;

byte rr = 0;
byte rg = 0;
byte rb = 0;
byte rw = 0;

byte neighbours[30][4];
byte tiles[30];
byte tilesComp[30];

const int MODE_OFF = 0;
const int MODE_BWFLICKER = 1;
const int MODE_COLORNOISE = 2;
const int MODE_GOL = 3;
const int MODE_BOOT = 4;
const int MODE_STREAMING = 99;
const int MODE_233 = 233;
int mode = MODE_BOOT;
int noSerial = 0;

byte param1 = 2;
byte param2 = 2;
byte param3 = 2;
byte param4 = 2;
byte param5 = 2;

byte bwintensity = 2;
byte noiseBrightnessR = maxBrightness;
byte noiseBrightnessG = maxBrightness;
byte noiseBrightnessB = maxBrightness;
byte noiseBrightnessW = maxBrightness;

const byte SERIAL_MODE = '0';
const byte SERIAL_PARAM1 = '1';
const byte SERIAL_PARAM2 = '2';
const byte SERIAL_PARAM3 = '3';
const byte SERIAL_PARAM4 = '4';
const byte SERIAL_PARAM5 = '5';
const byte SERIAL_GLOBAL1 = '101';
const byte SERIAL_GLOBAL2 = '102';
const byte SERIAL_GLOBAL3 = '103';
const byte SERIAL_GLOBAL4 = '104';
const byte SERIAL_GLOBAL5 = '105';

const byte PHASE_COMPUTE = 0;
const byte PHASE_TRANSITION = 1;
const byte PHASE_RANDOM = 2;
const byte PHASE_WAIT = 3;
const byte PHASE_STREAMING = 4;
const byte PHASE_OFF = 5;

byte phase = PHASE_COMPUTE;
int generation = 0;
int randomTime = 0;

int generationTime = 590;
int seedTime = 5000;
float transition = 0.0;

int aliveR = 2;
int aliveG = 3;
int aliveB = 3;
int aliveW = 3;

void setup() {
  Serial.begin(9600);

  ShiftPWM.SetPinGrouping(1);
  ShiftPWM.SetAmountOfRegisters(numRegisters);

  ShiftPWM.Start(pwmFrequency, maxBrightness);
  ShiftPWM.SetAll(0);

  initTiles();
  initNeighbours();

  randomSeed(1365363600);  //viki birthdate

  seed();
  draw();
}

void loop() {
  heartbeat++;
  compute();
  draw();
}

int tileInitNr = 0;

void initTiles() {
  for (int i = 0; i < 30; i++) {
    tiles[i] = B00000000;
    //tiles[i]|=DIR_1;
  }
  //tiles[0]|=LED_R;
  memcpy(tilesComp, tiles, sizeof(tiles));
}


void initNeighbours() {
  initTile(2, 3, 9, 10);
  initTile(3, 1, 14, 15);
  initTile(4, 5, 1, 2);
  initTile(5, 3, 17, 18);
  initTile(6, 7, 3, 4);
  initTile(7, 5, 20, 21);
  initTile(8, 9, 5, 6);
  initTile(9, 7, 23, 24);
  initTile(10, 1, 7, 8);
  initTile(11, 12, 1, 9);
  initTile(12, 10, 24, 25);
  initTile(13, 14, 10, 11);
  initTile(14, 12, 27, 28);
  initTile(15, 2, 12, 13);
  initTile(16, 17, 2, 14);
  initTile(17, 15, 28, 29);
  initTile(18, 5, 15, 16);
  initTile(19, 20, 4, 17);
  initTile(20, 18, 29, 30);
  initTile(21, 6, 18, 19);
  initTile(22, 23, 6, 20);
  initTile(23, 21, 30, 26);
  initTile(24, 8, 21, 22);
  initTile(25, 11, 8, 23);
  initTile(26, 27, 11, 24);
  initTile(27, 25, 22, 30);
  initTile(28, 13, 25, 26);
  initTile(29, 16, 13, 27);
  initTile(30, 19, 16, 28);
  initTile(26, 22, 19, 29);
}

void initTile(byte n1, byte n2, byte n3, byte n4) {
  neighbours[tileInitNr][N1] = n1 - 1;
  neighbours[tileInitNr][N2] = n2 - 1;
  neighbours[tileInitNr][N3] = n3 - 1;
  neighbours[tileInitNr][N4] = n4 - 1;
  tileInitNr++;
}


void seed() {
  for (int ti = 0; ti < 30; ti++) {
    tiles[ti] = random(125);
    ShiftPWM.SetRGBWsimple(ti, maxBrightness, maxBrightness, maxBrightness, maxBrightness);
  }
  memcpy(tilesComp, tiles, sizeof(tiles));
}


boolean allDeadR() {
  for (int ti = 0; ti < 30; ti++) {
    if (tiles[ti] & LED_R == LED_R) return false;
  }
  return true;
}


void compute() {
  if (phase == PHASE_COMPUTE) {

    for (int ti = 0; ti < 30; ti++) {
      byte nnr = 0;
      byte nng = 0;
      byte nnb = 0;
      byte nnw = 0;

      for (int ne = 0; ne < 4; ne++) {
        byte neighbour = tiles[neighbours[ti][ne]];
        if ((neighbour & LED_R) == LED_R) nnr++;
        if ((neighbour & LED_G) == LED_G) nng++;
        if ((neighbour & LED_B) == LED_B) nnb++;
        if ((neighbour & LED_W) == LED_W) nnw++;
      }

      if ((tiles[ti] & DIR_1) == DIR_1)
        if ((tiles[ti] & LED_R) == LED_R) {
          nng++;
          nnb++;
          nnw++;
        }
      if ((tiles[ti] & DIR_2) == DIR_2)
        if ((tiles[ti] & LED_G) == LED_G) {
          nnr++;
          nnb++;
          nnw++;
        }
      if ((tiles[ti] & DIR_3) == DIR_3)
        if ((tiles[ti] & LED_B) == LED_B) {
          nnr++;
          nng++;
          nnw++;
        }
      if ((tiles[ti] & DIR_4) == DIR_4)
        if ((tiles[ti] & LED_W) == LED_W) {
          nnr++;
          nng++;
          nnb++;
        }



      if ((tiles[ti] & LED_R) == LED_R) {
        if (nnr < aliveR - 1) tilesComp[ti] ^= LED_R;
        else if (nnr >= aliveR + 1) tilesComp[ti] ^= LED_R;
      } else {
        if (nnr == aliveR) tilesComp[ti] ^= LED_R;
      }

      if ((tiles[ti] & LED_G) == LED_G) {
        if (nng < aliveG - 1) tilesComp[ti] ^= LED_G;
        else if (nng >= aliveG + 1) tilesComp[ti] ^= LED_G;
      } else {
        if (nng == aliveG) tilesComp[ti] ^= LED_G;
      }

      if ((tiles[ti] & LED_B) == LED_B) {
        if (nnb < aliveB - 1) tilesComp[ti] ^= LED_B;
        else if (nnb >= aliveB + 1) tilesComp[ti] ^= LED_B;
      } else {
        if (nnb == aliveB) tilesComp[ti] ^= LED_B;
      }

      if ((tiles[ti] & LED_W) == LED_W) {
        if (nnw < aliveW - 1) tilesComp[ti] ^= LED_W;
        else if (nnw >= aliveW + 1) tilesComp[ti] ^= LED_W;
      } else {
        if (nnw == aliveW) tilesComp[ti] ^= LED_W;
      }
    }

    phase = PHASE_TRANSITION;
    transition = 0.0;

  } else if (phase == PHASE_TRANSITION) {
    float transfactor = (float)maxBrightness / (float)generationTime;
    transition += transfactor;

    if (transition >= (float)maxBrightness) {
      transition = maxBrightness;
      phase = PHASE_COMPUTE;
      memcpy(tiles, tilesComp, sizeof(tilesComp));
    }
  }
}


void draw() {
  checkInput();
  if (mode == MODE_233) {
    for (int ti = 0; ti < 30; ti++) {
      rr = random(noiseBrightnessR);
      rg = random(noiseBrightnessG);
      rb = random(noiseBrightnessB);
      rw = random(noiseBrightnessW);
      ShiftPWM.SetRGBWsimple(ti, rr, 0, 0, 0);
    }
  } else if (mode == MODE_COLORNOISE) {
    for (int ti = 0; ti < 30; ti++) {
      rr = random(noiseBrightnessR);
      rg = random(noiseBrightnessG);
      rb = random(noiseBrightnessB);
      rw = random(noiseBrightnessW);
      ShiftPWM.SetRGBWsimple(ti, rr, rg, rb, rw);
    }
  } else if (mode == MODE_BWFLICKER) {
    for (int ti = 0; ti < 30; ti++) {
      //rr = random(bwintensity);
      //rg = random(bwintensity);
      //rb = random(bwintensity);
      rw = random(bwintensity);
      ShiftPWM.SetRGBWsimple(ti, 0, 0, 0, rw);
    }
  } else if (mode == MODE_GOL) {
    if (heartbeat % seedTime == 0) {
      int aliveR2 = aliveR;
      aliveR = aliveG;
      aliveG = aliveB;
      aliveB = aliveW;
      aliveW = aliveR;

      seed();
      //phase=PHASE_RANDOM;
    }

    for (int ti = 0; ti < 30; ti++) {
      byte tilesR = (tiles[ti] & LED_R) == LED_R;
      byte tilesG = (tiles[ti] & LED_G) == LED_G;
      byte tilesB = (tiles[ti] & LED_B) == LED_B;
      byte tilesW = (tiles[ti] & LED_W) == LED_W;

      byte tilesCompR = (tilesComp[ti] & LED_R) == LED_R;
      byte tilesCompG = (tilesComp[ti] & LED_G) == LED_G;
      byte tilesCompB = (tilesComp[ti] & LED_B) == LED_B;
      byte tilesCompW = (tilesComp[ti] & LED_W) == LED_W;

      byte r = getTransition(tilesR, tilesCompR);
      byte g = getTransition(tilesG, tilesCompG);
      byte b = getTransition(tilesB, tilesCompB);
      byte w = getTransition(tilesW, tilesCompW);

      ShiftPWM.SetRGBWsimple(ti, r, g, b, w);
      //ShiftPWM.SetRGBWsimple(ti,r,0,0,0);
    }
  } else if (mode == MODE_OFF) {
    for (int ti = 0; ti < 30; ti++) {
      ShiftPWM.SetRGBWsimple(ti, 0, 0, 0, 0);
    }
  } else if (mode == MODE_BOOT) {
    bootLeds();
  }
}


byte getTransition(byte t, byte tc) {
  if (t + tc == 2) return maxBrightness;
  else if (t - tc == 1) return maxBrightness - (int)transition;
  else if (t - tc == -1) return (int)transition;
  return 0;
}




/***********************************************/
static uint8_t y8 = 1;
static uint16_t y16 = 1;

// returns values from 1 to 255 inclusive, period is 255
uint8_t xorshift8(void) {
  y8 ^= (y8 << 7);
  y8 ^= (y8 >> 5);
  return y8 ^= (y8 << 3);
}

// returns values from 1 to 65535 inclusive, period is 65535
uint16_t xorshift16(void) {
  y16 ^= (y16 << 13);
  y16 ^= (y16 >> 9);
  return y16 ^= (y16 << 7);
}

/***********************************************/
/* SERIAL INPUT                                */
/***********************************************/
const int STATE_UNKNOWN = -1;
const int STATE_MODE = 0;
const int STATE_PARAM = 1;
int state = STATE_UNKNOWN;

int paramnum = 0;
int field = 0;
boolean readNumber = false;
int number = 0;

int bootbright = maxBrightness;
float bootspeed = 0.1663195;


void checkInput() {
  //if(Serial.available()>0){
  while (Serial.available() > 0) {
    byte val = Serial.read();

    if (val == 'm') {
      state = STATE_MODE;
      readNumber = false;  //really needed?
    } else if (val == 'p') {
      field = 0;
      state = STATE_PARAM;
      readNumber = false;  //really needed?
      Serial.println("received p");
    }

    if (val == ',') {
      parseParam();
      readNumber = false;
    }

    if ((val >= 48) && (val <= 57)) {
      if (!readNumber) number = 0;
      readNumber = true;
      number = (number * 10) + (val - '0');
    }

    if (val == ';') {
      if (state == STATE_MODE) {
        if (!readNumber) {
          Serial.println("expected mode, no number read!");
        } else {
          mode = number;
          Serial.print("set mode to ");
          Serial.println(number);
          state = STATE_UNKNOWN;
        }
      } else if (state == STATE_PARAM) {
        parseParam();
      }
    }
  }
}

void parseParam() {
  if (readNumber) {
    if (state = STATE_PARAM) {
      if (mode == MODE_GOL) {
        if (field == 0) seedTime = number * 50;
        if (field == 1) generationTime = number * 5;
      } else if (mode == MODE_BWFLICKER) {
        if (field == 0) bwintensity = number;
      } else if (mode == MODE_COLORNOISE) {
        if (field == 0) noiseBrightnessR = min(number, maxBrightness);
        if (field == 1) noiseBrightnessG = min(number, maxBrightness);
        if (field == 2) noiseBrightnessB = min(number, maxBrightness);
        if (field == 3) noiseBrightnessW = min(number, maxBrightness);
      } else if (mode == MODE_BOOT) {
        if (field == 0) bootbright = number;
        if (field == 1) bootspeed = 21.0 / (float)(number + 1);
      }
      Serial.print("set param to ");
      Serial.println(number);
      field++;
    }
  }
}




/*
void checkInput(){
  if(mode==MODE_STREAMING){
    noSerial++;

    if(noSerial>=100){
      mode=MODE_BWFLICKER;
      noSerial=0;
      Serial.flush();
    }
    
    if (Serial.available()>=32) {
      noSerial=0;
      byte channel = Serial.read();
      for(int ti=0;ti<30;ti++){
        byte streamcolor = Serial.read();
        byte r,g,b,w;
        r=0;g=0;b=0;w=0;
        if(channel==0){
          r=streamcolor;
        }else if(channel==1){
          g=streamcolor;
        }else if(channel==2){
          b=streamcolor;
        }else if(channel==3){
          w=streamcolor;
        }
        ShiftPWM.SetRGBWsimple(ti,r,g,b,w);
      }
      byte endStreaming = Serial.read();
      if(endStreaming!='0'){
        mode=MODE_OFF;
      }
    }
  }else{
    if(Serial.available()>=2){
      byte serialId = Serial.read();
      byte serialValue = Serial.read();
      
      if(serialId==SERIAL_MODE){
        mode=serialValue;
      }
      else if(serialId==SERIAL_PARAM1){
        if(mode==MODE_GOL)seedTime=serialValue*50;
        else if(mode==MODE_BWFLICKER)bwintensity=serialValue;
        else if(mode==MODE_COLORNOISE)noiseBrightnessR=max(serialValue,maxBrightness);
        param1=serialValue;
      }else if(serialId==SERIAL_PARAM2){
        if(mode==MODE_GOL)generationTime=serialValue*5;
        else if(mode==MODE_BWFLICKER)bwintensity=serialValue;
        else if(mode==MODE_COLORNOISE)noiseBrightnessG=max(serialValue,maxBrightness);
        param2=serialValue;
      }else if(serialId==SERIAL_PARAM3){
        if(mode==MODE_COLORNOISE)noiseBrightnessB=max(serialValue,maxBrightness);
        //if(mode==MODE_GOL)aliveR=1;
        param3=serialValue;
      }else if(serialId==SERIAL_PARAM4){
        if(mode==MODE_COLORNOISE)noiseBrightnessW=max(serialValue,maxBrightness);
        param4=serialValue;
      }else if(serialId==SERIAL_PARAM5){
        param5=serialValue;
      }else{
        //Serial.flush();
      }
    }
  }
}

*/



/******** additional modes ********/


float tr = 0.0;
float tg = 0.0;
float tb = 0.0;
float tw = 0.0;

int bl1 = 0;
int bl2 = 0;
int bl3 = 0;
int bl4 = 0;
int bl5 = 0;
int bl6 = 0;

int currentLED = 0;


int ledrows36[] = {
  1, 2, 3, 1, 2, 3,
  4, 5, 9, 10, 14, 15,
  7, 12, 17, 7, 12, 17,
  6, 8, 11, 13, 16, 18,
  20, 24, 28, 20, 24, 28,
  19, 21, 23, 25, 27, 29,
  22, 26, 30, 22, 26, 30
};
float bootY = 0.0;
int bootC = 0;
float speedy = 0.0;


void bootLeds() {
  bootY += 0.1669314;  //+(bootC/50.0);
  if (bootY < -2) bootY = 9.0;
  if (bootY > 9.0) {
    bootY = -2.0;
    bootC++;
    if (bootC > 11) bootC = 0;
  }
  int by = (int)bootY;
  float bright = 0.0;
  int br = 0;
  int dr = 0;
  for (int i = 0; i < 42; i++) {
    float brbr = (float)min(bootbright, maxBrightness);
    if (i % 6 == 0) {
      bright = abs((bootY - ((i / 6) + 0.5)) * 0.27);
      if (bright <= 1.0) {
        bright = abs(bright - 1.0);
        bright *= bright;
        bright = abs(bright - 1.0);
        br = brbr - (int)(bright * brbr);
      } else {
        br = 0;
      }
    }
    if (br > brbr) br = brbr;
    if (br < 0) br = 0;
    dr = brbr - br;
    setLedTest(i, br, dr);
  }
}
void setLedTest(int lnr, int bbr, int ddr) {
  int c1 = 0;
  int c2 = 0;
  int c3 = 0;
  int c4 = 0;
  if ((bootC % 4) == 0) c1 = bbr;
  if ((bootC % 4) == 1) c2 = bbr;
  if ((bootC % 4) == 2) c3 = bbr;
  if ((bootC % 4) == 3) c4 = bbr;
  ShiftPWM.SetRGBWsimple(ledrows36[lnr] - 1, c1, c2, c3, c4);
}

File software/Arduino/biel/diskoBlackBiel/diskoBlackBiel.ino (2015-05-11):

// set pin numbers:

//output 1,5,3,4
#include <math.h>
#include <TimerOne.h>
#include <TimerThree.h>
#include <EEPROM.h>

const int EEPROM_OFFSET=1024;
const int DIMENSION = 32;
const int UNDEFINED=255;



//BATMAN!!!

volatile const int lamp [] = {
                  9, 10, 8, 11, 7, 12, 6, 13,
                  22,21,24,20,26,19,28,18,
                  32,30,36,34,40,38,44,42,
                  33,31,37,35,41,39,45,43
};

/*
//KYLIE!!!
volatile const int lamp [] = {  9, 10, 8, 11, 7, 12, 6, 13,
                  24, 26, 21, 20, 28, 19, 30, 18,
                  32, 38, 36, 40, 42, 39, 41, 43,
                  45, 47, 33, 35, 37, 44, 46, 34 
                };
*/


int preset[32];
int lampPos=0;
int presetPos=0;
boolean isSetup=false;
int sequence=0;
int oldSeq=-1;
int seqFade=0;

//int phase=0;

volatile float sinus=10.0;



int selectBright=50;


volatile int dim [] =  {99, 99, 99, 99, 99, 99, 99, 99, 99, 99, 99, 99, 99, 99, 99, 99, 99, 99, 99, 99, 99, 99, 99, 99, 99, 99, 99, 99, 99, 99, 99, 99};
volatile int wait [] =  {99, 99, 99, 99, 99, 99, 99, 99, 99, 99, 99, 99, 99, 99, 99, 99, 99, 99, 99, 99, 99, 99, 99, 99, 99, 99, 99, 99, 99, 99, 99, 99};

volatile int lust = 0;
volatile int maxlust = 100;


volatile int numBulbs=32;
volatile int bright=67;
volatile int toBright=67;

volatile int decr=35;
volatile int toDecr=35;

volatile float speedi=0.037;
volatile float toSpeed=speedi;

int heartbeat=0;
int hb=0;

volatile boolean fire[32];
volatile int z=0;

long bfire = B00000000;
float sine[515];

const int freqStep = 75;    // Set the delay for the frequency of power (65 for 60Hz, 78 for 50Hz) per step (using 128 steps)

boolean switcher=false;
boolean strobe=false;

int strobeCount=0;
int strobeFreq=2;

/** logic variables */
float count=2*PI;
int fadeSpeed=50;

int micPin = 4;


boolean isSine=false;

/******* cellular *******/
volatile int maxBrightness = 50;

const byte CELL  = B10000000;
const byte DIR_1 = B01000000;
const byte DIR_2 = B00100000;
const byte DIR_3 = B00010000;
const byte DIR_4 = B00001000;
const byte DIR_5 = B00000100;
const byte DIR_6 = B00000010;
const byte RAND  = B00000001;

byte rr=0;
byte rg=0;
byte rb=0;
byte rw=0;
byte neighbours[32][4];
byte tiles[32];
byte tilesComp[32];

const byte PHASE_COMPUTE = 0;
const byte PHASE_TRANSITION = 1;
const byte PHASE_RANDOM = 2;
const byte PHASE_WAIT = 3;

byte phase = PHASE_RANDOM;
int generation=0;
int randomTime=0;

const int generationTime = 50;
const int seedTime = 2000;
float transition = 0.0;

int tileInitNr=0;

boolean isCellular=true;

b



void setup() {
  Serial.begin(9600);
  Serial3.begin(9600);
  
  setupSine();
  /*
  Serial.println("clear Presets");
  clearPreset();
  */
  Serial.println("init Presets");
  Serial3.println("booting 3....");
  initPreset();
  loadPreset();
  for (int i = 0;i<numBulbs; i++) {
    fire[i]=false;
    pinMode(lamp[i], OUTPUT);  
    digitalWrite(lamp[i],LOW); 
  }
  attachInterrupt(1, zero_cross_detect, RISING);   // Attach an Interupt to Pin 2 (interupt 0) for Zero Cross Detection

  Timer3.initialize(freqStep);
  Timer3.setPeriod(freqStep);
  Timer3.attachInterrupt(dim_check2);
  
  
  /***** cellular *****/
  initTiles();
  initNeighbours();
  
  randomSeed(1365363600);
  
  seed();

}


/***** cellular *****/

void initTiles(){
  for(int i=0; i<30; i++){
    tiles[i]=B00000000;
  }
  memcpy(tilesComp,tiles,sizeof(tiles));
}


void initNeighbours(){
  initTile(1,2,3,4,5,99);

  initTile(0,5,6,12,7,2);
  initTile(0,1,7,13,8,3);
  initTile(0,2,8,14,9,4);
  initTile(0,3,9,15,10,5);
  initTile(0,4,10,11,6,1);

  initTile(1,5,11,17,12,99);
  initTile(2,1,12,18,13,99);
  initTile(3,2,13,19,14,99);
  initTile(4,3,14,20,15,99);
  initTile(5,4,15,16,11,99);

  initTile(5,10,16,22,17,6);
  initTile(1,6,17,23,18,7);
  initTile(2,7,18,24,19,8);
  initTile(3,8,19,25,20,9);
  initTile(4,9,20,21,16,10);

  initTile(10,15,21,27,22,11);
  initTile(6,11,22,28,23,12);
  initTile(7,12,23,29,24,13);
  initTile(8,13,24,30,25,14);
  initTile(9,14,25,26,21,15);

  initTile(15,20,26,27,16,99);
  initTile(11,16,27,28,17,99);
  initTile(12,17,28,29,18,99);
  initTile(13,18,29,30,19,99);
  initTile(14,19,30,26,20,99);

  initTile(20,25,30,31,27,21);
  initTile(16,21,26,31,28,22);
  initTile(17,22,27,31,29,23);
  initTile(18,23,28,31,30,24);
  initTile(19,24,29,31,26,25);

  initTile(26,27,28,29,30,99);
  
}

void initTile(byte n1, byte n2, byte n3, byte n4, byte n5, byte n6){
  neighbours[tileInitNr][0]=n1;
  neighbours[tileInitNr][1]=n2;
  neighbours[tileInitNr][2]=n3;
  neighbours[tileInitNr][3]=n4;
  neighbours[tileInitNr][4]=n5;
  neighbours[tileInitNr][5]=n6;
  tileInitNr++;
}

void seed(){
  for(int ti=0; ti<32; ti++){
    tiles[ti]=random(255);
  }
  memcpy(tilesComp,tiles,sizeof(tiles));
}

void compute(){
  if(phase==PHASE_COMPUTE){
 
    for(int ti=0; ti<32; ti++){
      byte nAlive = 0;
      
      for(int ne=0; ne<6; ne++){
        byte nIndex = neighbours[ti][ne];
        if(nIndex!=99){
          byte neighbour = tiles[nIndex];
          if((neighbour&CELL)==CELL)nAlive++;
        }
      }
      
      if((tiles[ti]&CELL)==CELL){
        if(nAlive<2)tilesComp[ti]^=CELL;
        else if(nAlive>=4)tilesComp[ti]^=CELL;
      }else{
        if(nAlive==3)tilesComp[ti]^=CELL;
      }
      
    }
    
    phase=PHASE_TRANSITION;
    transition=0.0;
    
  }else if(phase==PHASE_TRANSITION){
    float transfactor=(float)maxBrightness/(float)generationTime;
    transition+=transfactor;
    
    if(transition>=(float)maxBrightness){
      transition=maxBrightness;
      phase=PHASE_COMPUTE;
      memcpy(tiles,tilesComp,sizeof(tilesComp));
    }

  }
}

float testBrightf=60.0f;

void drawCells(){
  if(phase==PHASE_RANDOM){
    
    runStrobe();
    
    randomTime++;
    if(randomTime>50){
      count=1234.5;
      speedi=12.98776543;
      randomTime=0;
      phase=PHASE_COMPUTE;
      seed();
    }
  }else if(phase==PHASE_WAIT){
    runSine();
    /*
    for(int ti=0; ti<32; ti++){
      dim[ti]=120;
      fire[ti]=true;
    }*/
  }else{
    testBrightf+=0.1;
    int testBright = (int)testBrightf;
    
    for(int ti=0; ti<32; ti++){
      
      byte tilesCell = (tiles[ti]&CELL)==CELL;
      
      byte tilesCompCell = (tilesComp[ti]&CELL)==CELL;
      
      byte intensity = getTransition(tilesCell,tilesCompCell);
      
      //dim[ti]=intensity;
      dim[ti]=67+(maxBrightness-intensity);
      fire[ti]=true;
    }
  }
}

byte getTransition(byte t, byte tc){
  if(t+tc==2) return maxBrightness;
  else if(t-tc==1) return maxBrightness-(int)transition;
  else if(t-tc==-1) return (int)transition;
  return 0;
}









/** function to be fired at the zero crossing */
void zero_cross_detect() {
  heartbeat++;
  if(isSetup){
    runSetup();
  }else if(strobe){
    runStrobe();
  }else if(isSine){
    runSine();
  }else if(isCellular){
    compute();
    drawCells();

    if(heartbeat%seedTime==0){
      seed();
      phase=PHASE_RANDOM;
    }
  }
  z = 0;
}
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

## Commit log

2014-05-03 git init + 3d model
    [diskohedron-emission-frames.skp, piramida-bb.stl, piramida.skp]
2014-05-03 added pcb
    [diskohedron4w_hermaphrodit.brd, diskohedron4w_hermaphrodit.sch, diskohedron4w_pinheaders.brd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]
2014-05-03 updated pcb
    [diskohedron4w_hermaphrodit.brd, diskohedron4w_hermaphrodit.sch]
2014-05-04 first pcb freeze
    [diskohedron-powersupply.skp, diskohedron4w_hermaphrodit.brd, diskohedron4w_hermaphrodit.dwg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]
2014-05-06 rev. a almost fixed, first gerber-cam process
    [diskohedron4w_hermaphrodit.GBL, diskohedron4w_hermaphrodit.GBO, diskohedron4w_hermaphrodit.GBP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]
2014-05-06 updated gerbers
    [diskohedron4w_hermaphrodit.brd, diskohedron4w_hermaphrodit.sch]
2014-05-09 last commit before changing physical dimension
    [diskohedron4w_hermaphrodit.brd, diskohedron4w_hermaphrodit.sch]
2014-05-11 order for itead 12/05/2014 #100029337
    [diskohedron4w_hermaphrodit-plug_positions_R12.dxf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]
2014-05-24 remodelled the bottom with a big hole and corners for attaching pcb rev. a
2014-05-29 first commit for rev.b after wrong hermaphrodite spotting
    [diskohedron4w_revb.brd, diskohedron4w_revb.sch]
2014-05-31 changed output bridges to SMD pads, some cleanup, some labelling for bsilk
    [diskohedron4w_revb.brd, diskohedron4w_revb.sch]
2014-05-31 cleanup rev.b swapped single line driver to bottom side
    [diskohedron4w_revb.GBL, diskohedron4w_revb.GBO, diskohedron4w_revb.GBP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]
2014-06-01 digital line driver and receiver swapped to bottom, major redesign
    [diskohedron4w_revb.brd, diskohedron4w_revb.sch]
2014-06-01 further cleaning, added bottomlayer cream masks for smd bridges
    [diskohedron4w_revb.brd, diskohedron4w_revb.sch]
2014-06-06 order itead for rev.b and 3d trio unique model
    [diskohedron4w_revb.GBL, diskohedron4w_revb.GBO, diskohedron4w_revb.GBP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]
2014-06-07 cleaning pcb dir
    [piramida-revB-utility.stl, piramida-revB.stl]
2014-06-07 added powersupply dwg
    [PowerSupply.dwg]
2014-06-08 power unit cone before murging objects
2014-06-16 first draft of rev. c with switchable input/output
    [diskohedron4w_revc.brd, diskohedron4w_revc.sch, partlist.ods]
2014-06-19 freezing gerber for rev.c, powercone 3d part
    [diskohedron4w_hermaphrodit-plug_positions_R12.dxf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]
2014-06-20 cleaned up schematic of rev.c
    [diskohedron4w_revc.sch]
2014-06-24 finished power unit UFO + L
    [piramida-revB-powerunit-3Dutility.stl, piramida-revB-powerunit-L-3Dutility.stl, piramida-revB-powerunit-L.stl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]
2014-07-08 cleanup revision b
    [diskohedron4w_revc.brd]
2014-07-10 edited stencil layout
    [revb_BcreamMirrored.dxf]
2014-07-10 stencil, acrylglass
    [PowerSupply.dwg, PowerSupply.dxf, diskohedron4w_revc.dxf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]
2014-07-17 initial commit phil (changed ShiftPWM library + diskoLEDron arduino sketch)
2014-08-02 documentation for mounting
    [diskohedron4w_revd.brd, diskohedron4w_revd.sch]
2014-09-01 added setRGBW(ledNumber, r, b, g, w)
2014-09-03 stencil files and partlist updated
    [partlist.ods, revc_revb_laser-layout.dwg]
2014-09-08 last modifications on the boxes made in july in vienna
    [piramida-revB-3dutility.stl, piramida-revB-duplo-3Dutility.stl]
2014-12-09 added lasercutting folder with a powerunitcone face (.dxf)
    [face-revB-powerunitcone.dxf]
2014-12-09 lasercutting powerunitcone dwg file
    [face-revB-powerunitcone.dwg]
2014-12-14 finally, the lasercutting file from the versalaser machine
    [face-revB-versalaser-sheet.dwg]
2014-12-30 rev.d and beagle upload scripts
    [BOM_diskohedron.xls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]
2015-02-18 added upload.sh script for remote upload of arduino hex files
    [partlist.ods]
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2015-02-25 added termination resistors for rev.c & d
    [diskohedron4w_revc.brd, diskohedron4w_revc_termination.brd, diskohedron4w_revc_termination.sch]
2015-03-02 added stencil for rev.d
    [diskohedron4w_revd.brd, revd_Bcream.dxf, revd_Tcream.dxf]
2015-03-05 added rev.E; changed CAPS To CASE G
    [diskohedron4w_reve.brd, diskohedron4w_reve.sch]
2015-03-26 changed to revF for itead order & modifed BOM list
    [BOM_diskohedron_revE.xls, BOM_diskohedron_revF.xls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]
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2015-03-28 dxf push push push
    [diskohedron4w_revf.dxf]
2015-03-28 ordered stl files for revB
    [piramida-revB-2boxes-3Dutility.stl, piramida-revB-powerunit-L-3Dutility-fixed.stl, piramida-revB-powerunit-L.stl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]
2015-03-28 revF ready for print; changed holes; created with Rhino
    [piramida-revF-test-mesh.stl]
2015-03-30 order in 3model stl folder
    [piramida-revB-duplo-3Dutility.stl, piramida-revB-powerunit-3Dutility.stl, piramida-revB-powerunit-L-3Dutility-fixed.stl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]
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2015-04-12 added assembly screenshot and small change in board silkscreen layout
    [diskohedron4w_revf.brd]
2015-04-14 added programs for biel (black + white), added DHT temperature sensor library
2015-04-16 mapping lightbulbs for zwarte de zwart, phil's hand > inkscape
2015-05-11 3D stuff
    [TeensyHolder108.stl, diskohedron-emission-frames-cutouts.skp, diskohedron4w_revf.dxf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]
2016-01-06 software cleanup + basel software
    [piramida-revB-3Dutility.stl, piramida-revB-3dutility.stl]
2016-01-06 first commit for app/www
    [TeensyHolder108.stl, diskohedron-emission-frames-cutouts.skp, diskohedron-emission-frames.skp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]
2016-01-06 further cleaning and making this comment for phil :)
    [TeensyHolder108.stl, diskohedron-emission-frames-cutouts.skp, diskohedron-emission-frames.skp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]
2016-01-07 fixing preset and added rgbw mode
    [diskoserver.js]
2016-01-11 3d construction files updates
    [standoff-13mm.stl, teensy-revision.stl]
2016-01-11 3d files updates, standoffs
    [piramida-revB-3dutility.stl, standoff-13mm.stl, teensy-revision.stl]
2025-01-06 fixing serialport js for new version
    [diskoserver.js]

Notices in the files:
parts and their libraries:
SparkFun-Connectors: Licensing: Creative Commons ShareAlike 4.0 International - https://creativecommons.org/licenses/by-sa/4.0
